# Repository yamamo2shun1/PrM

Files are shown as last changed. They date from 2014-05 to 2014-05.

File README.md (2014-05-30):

PrM
===

Modularized Analog mixer Controlled by Open Sound Control

License
---
<br /><span xmlns:dct="http://purl.org/dc/terms/" property="dct:title">PrM</span> is licensed under a <a rel="license" href="http://creativecommons.org/licenses/by-sa/4.0/">Creative Commons Attribution-ShareAlike 4.0 International License</a>.<br />Based on a work at <a xmlns:dct="http://purl.org/dc/terms/" href="https://github.com/tkrworks/PrM" rel="dct:source">https://github.com/tkrworks/PrM</a>.

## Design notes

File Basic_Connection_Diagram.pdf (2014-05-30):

Ch.1 | Ch.2

## Basic Module Connection Diagram

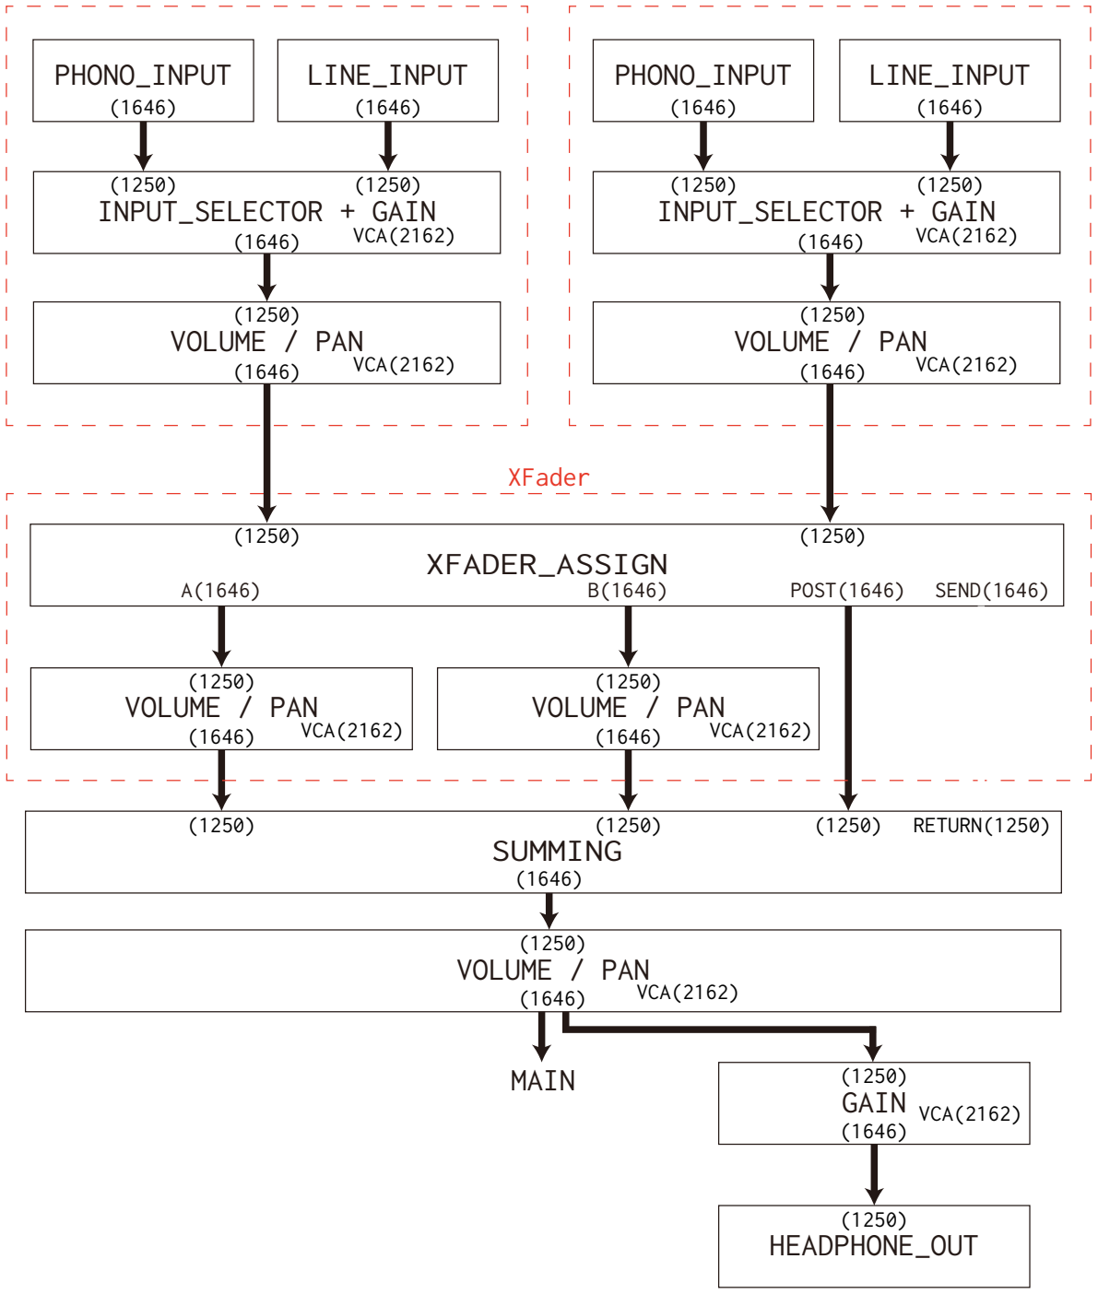
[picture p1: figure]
XFADER_ASSIGN; SUMMING; VOLUME / PAN; POST(1646) SEND(1646); MAIN; XFader; PHONO_INPUT (1646); LINE_INPUT (1646); (1250) RETURN(1250); INPUT_SELECTOR + GAIN (1646); VCA(2162); VOLUME / PAN (1646); HEADPHONE_OUT; GAIN (1646)

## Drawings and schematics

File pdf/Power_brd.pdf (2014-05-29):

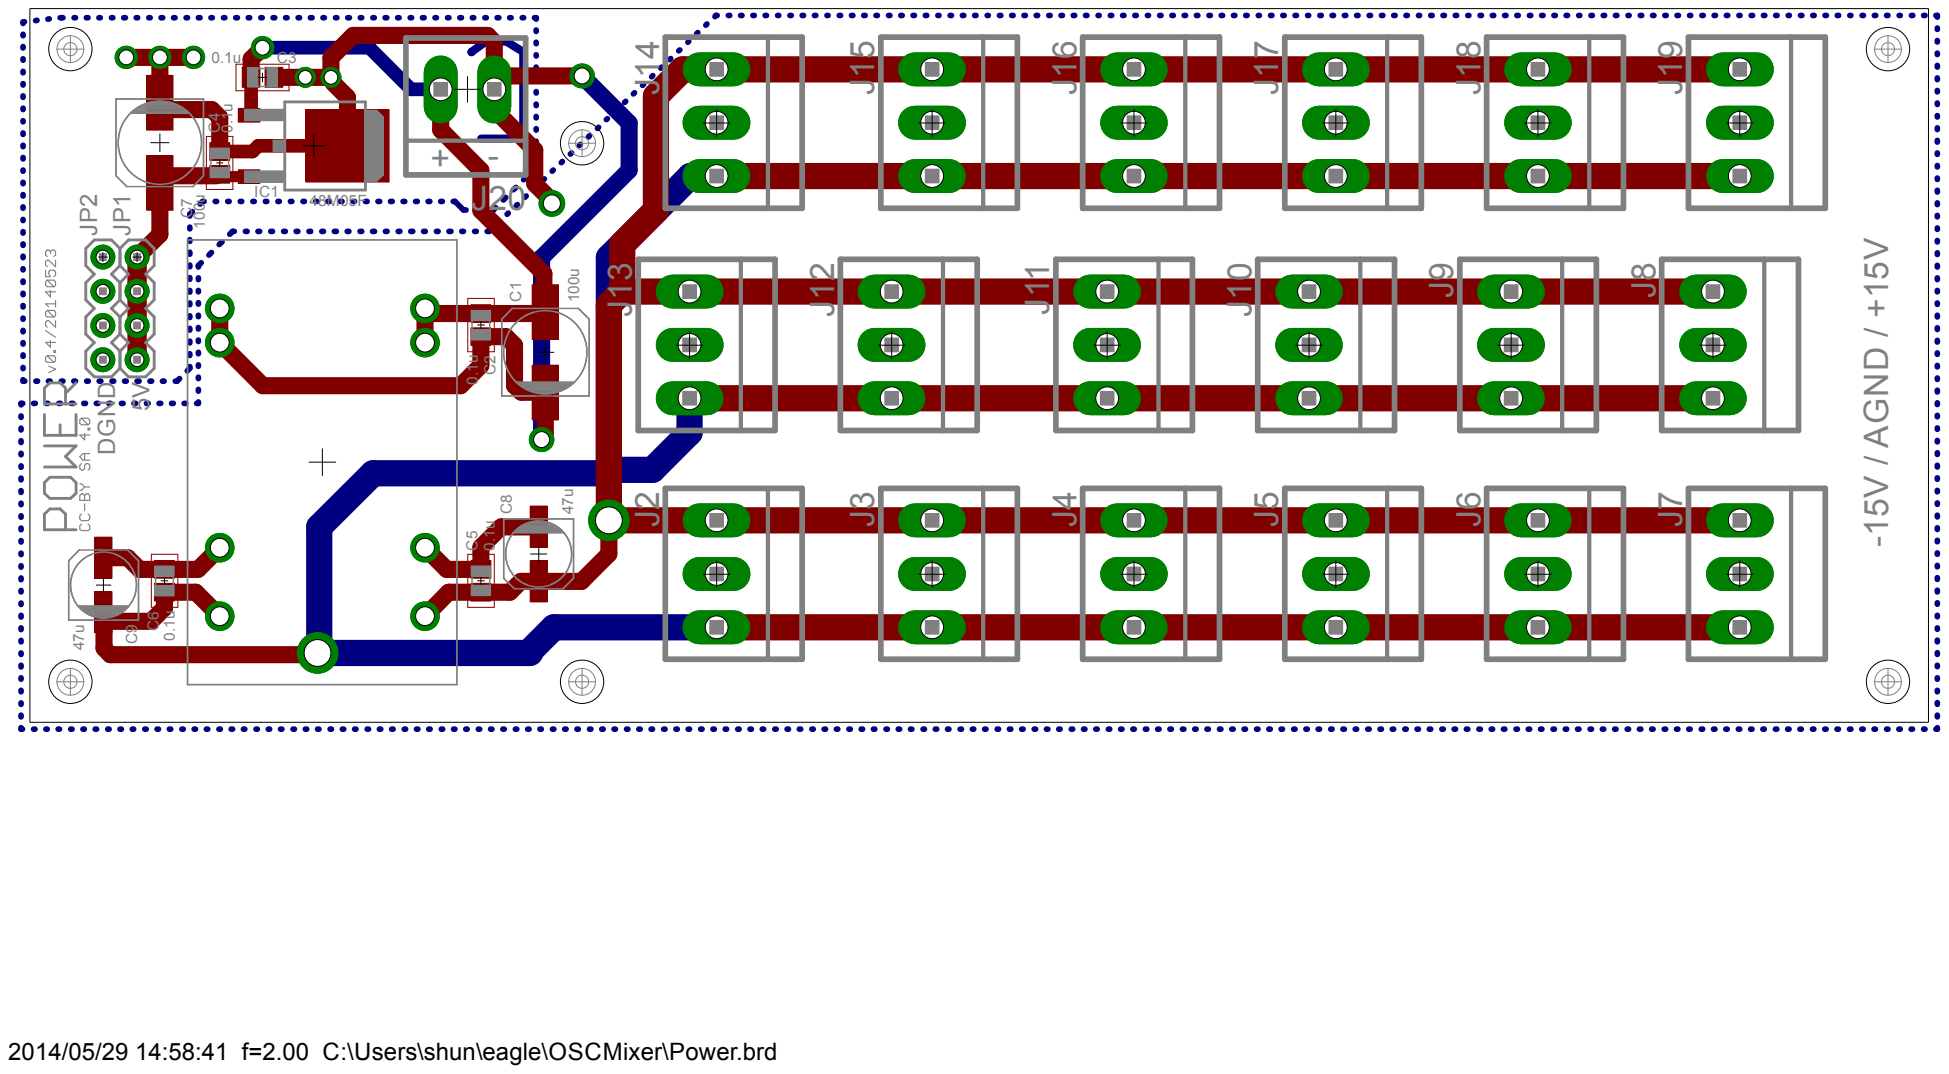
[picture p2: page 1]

2014/05/29 14:58:41 f=2.00 C:\Users\shun\eagle\OSCMixer\Power.brd

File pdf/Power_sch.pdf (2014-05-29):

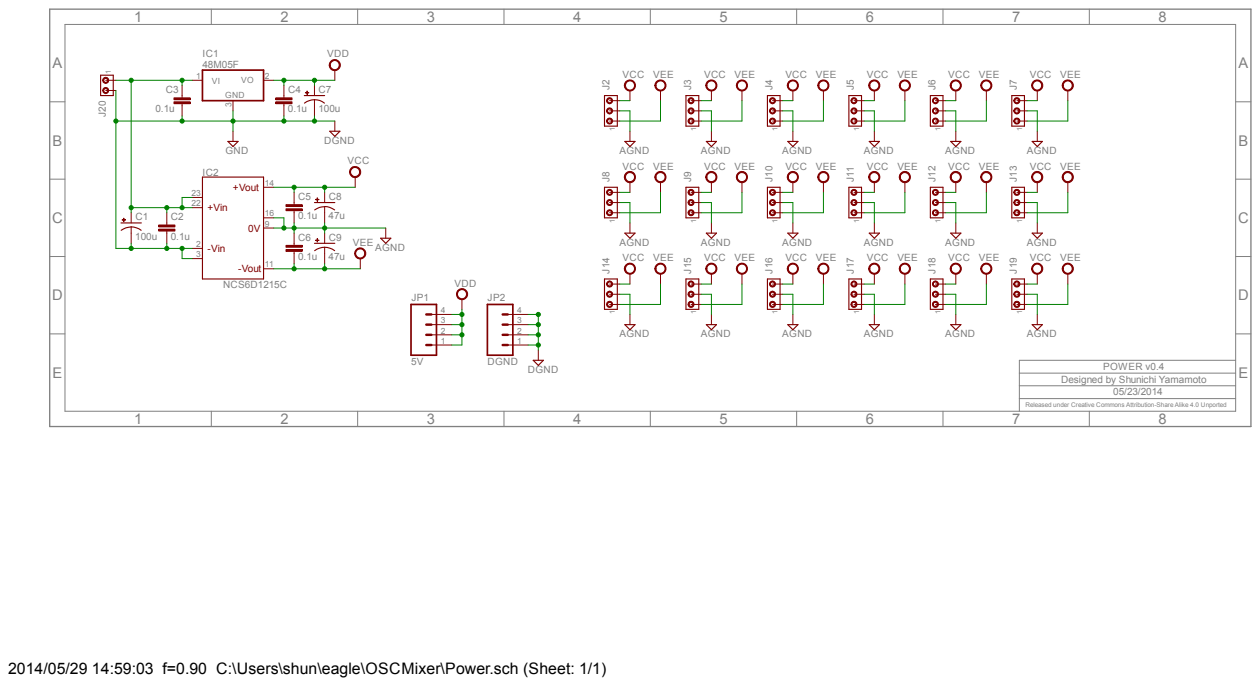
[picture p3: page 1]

Designed by Shunichi Yamamoto

Released under Creative Commons Attribution-Share Alike 4.0 Unported

2014/05/29 14:59:03 f=0.90 C:\Users\shun\eagle\OSCMixer\Power.sch (Sheet: 1/1)

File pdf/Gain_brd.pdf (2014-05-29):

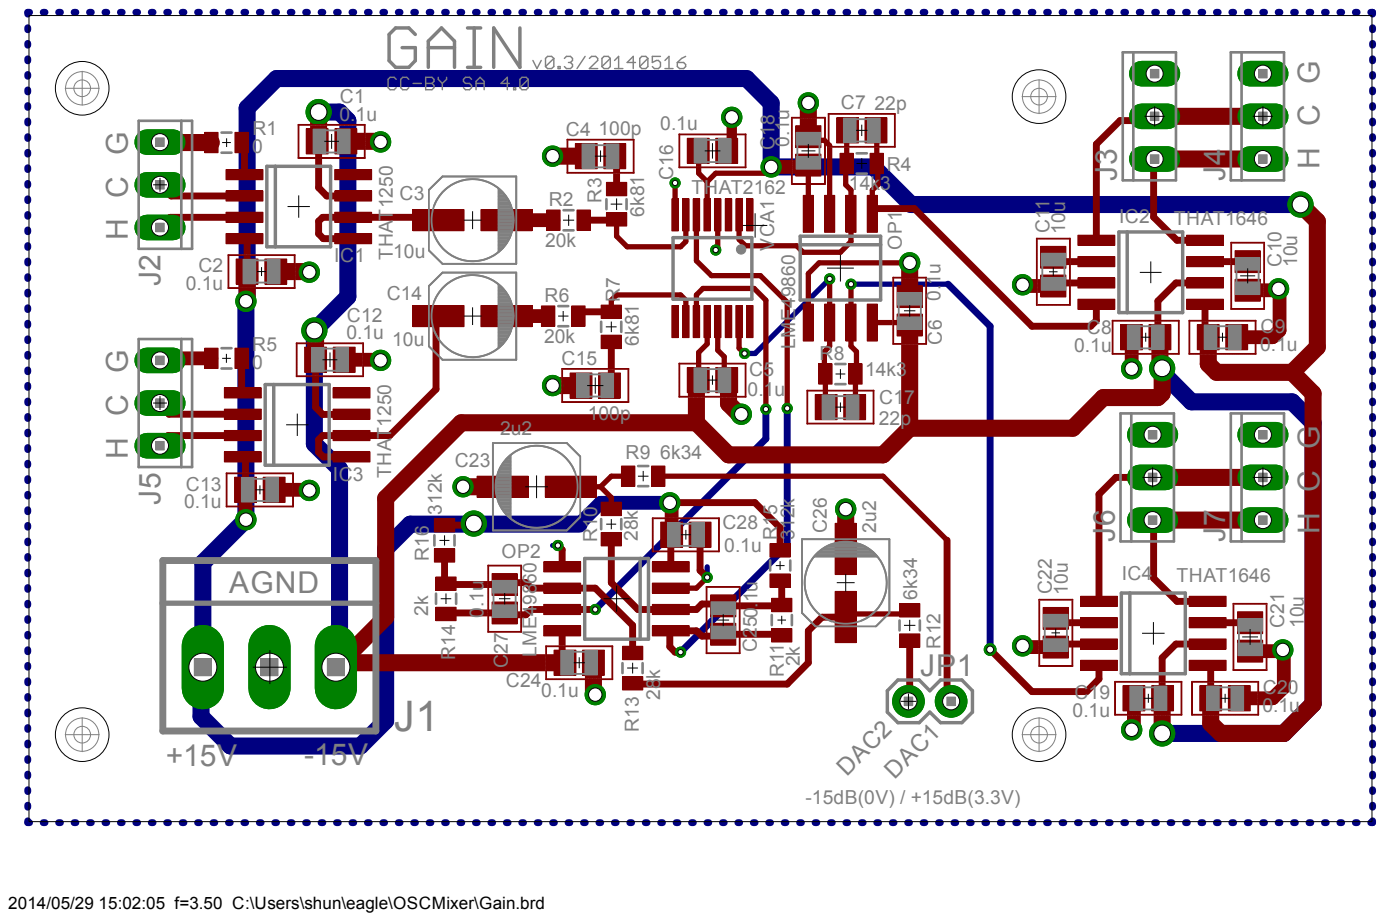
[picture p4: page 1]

2014/05/29 15:02:05 f=3.50 C:\Users\shun\eagle\OSCMixer\Gain.brd

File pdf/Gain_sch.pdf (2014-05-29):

1 | 2 | 3 | 4 | 5 | 6 | 7 | 8

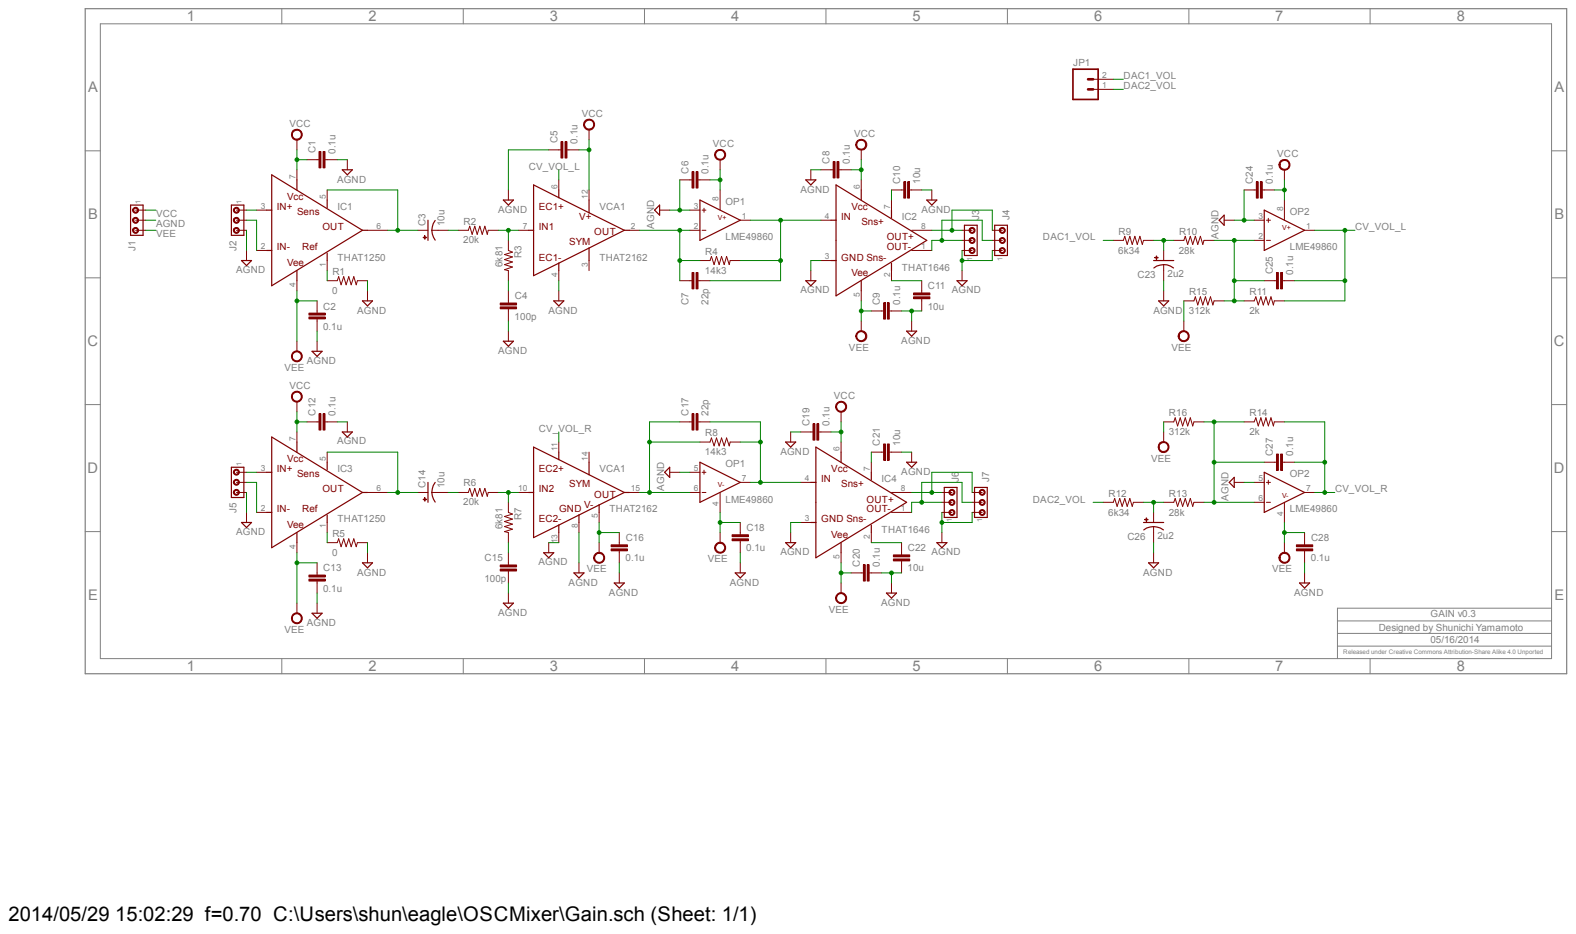
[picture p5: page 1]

Designed by Shunichi Yamamoto

Released under Creative Commons Attribution-Share Alike 4.0 Unported

2014/05/29 15:02:29 f=0.70 C:\Users\shun\eagle\OSCMixer\Gain.sch (Sheet: 1/1)

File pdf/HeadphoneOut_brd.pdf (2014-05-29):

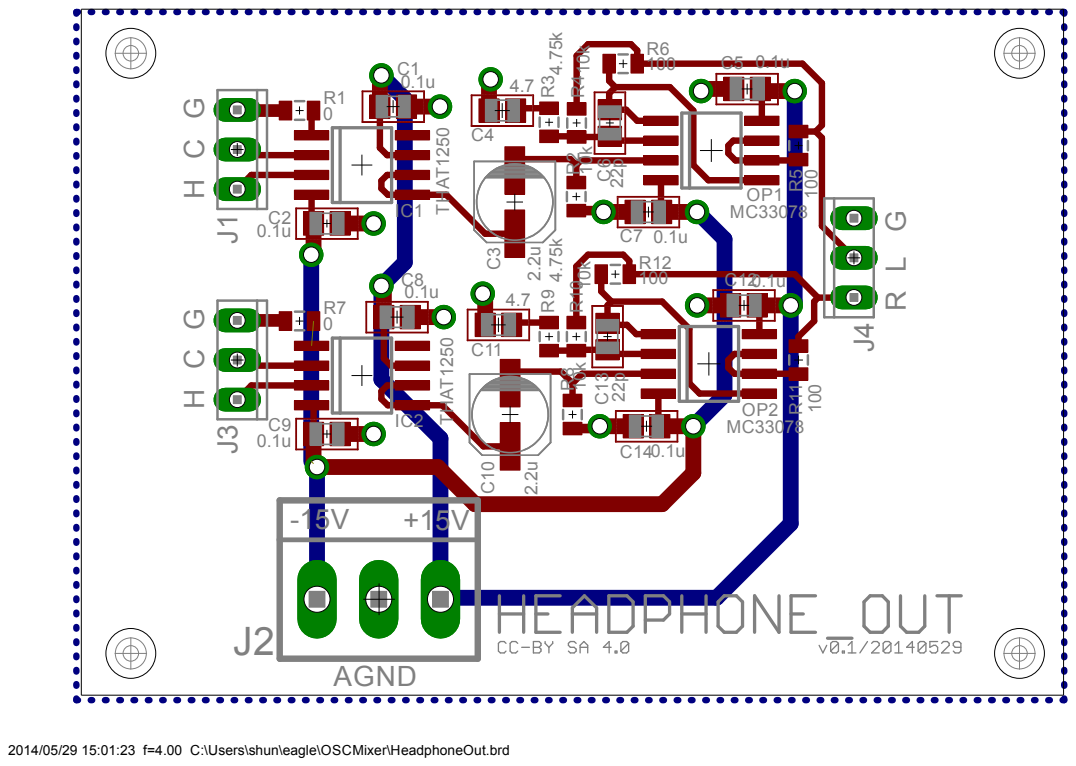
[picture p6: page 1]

2014/05/29 15:01:23 f=4.00 C:\Users\shun\eagle\OSCMixer\HeadphoneOut.brd

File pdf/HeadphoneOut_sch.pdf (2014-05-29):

A

A

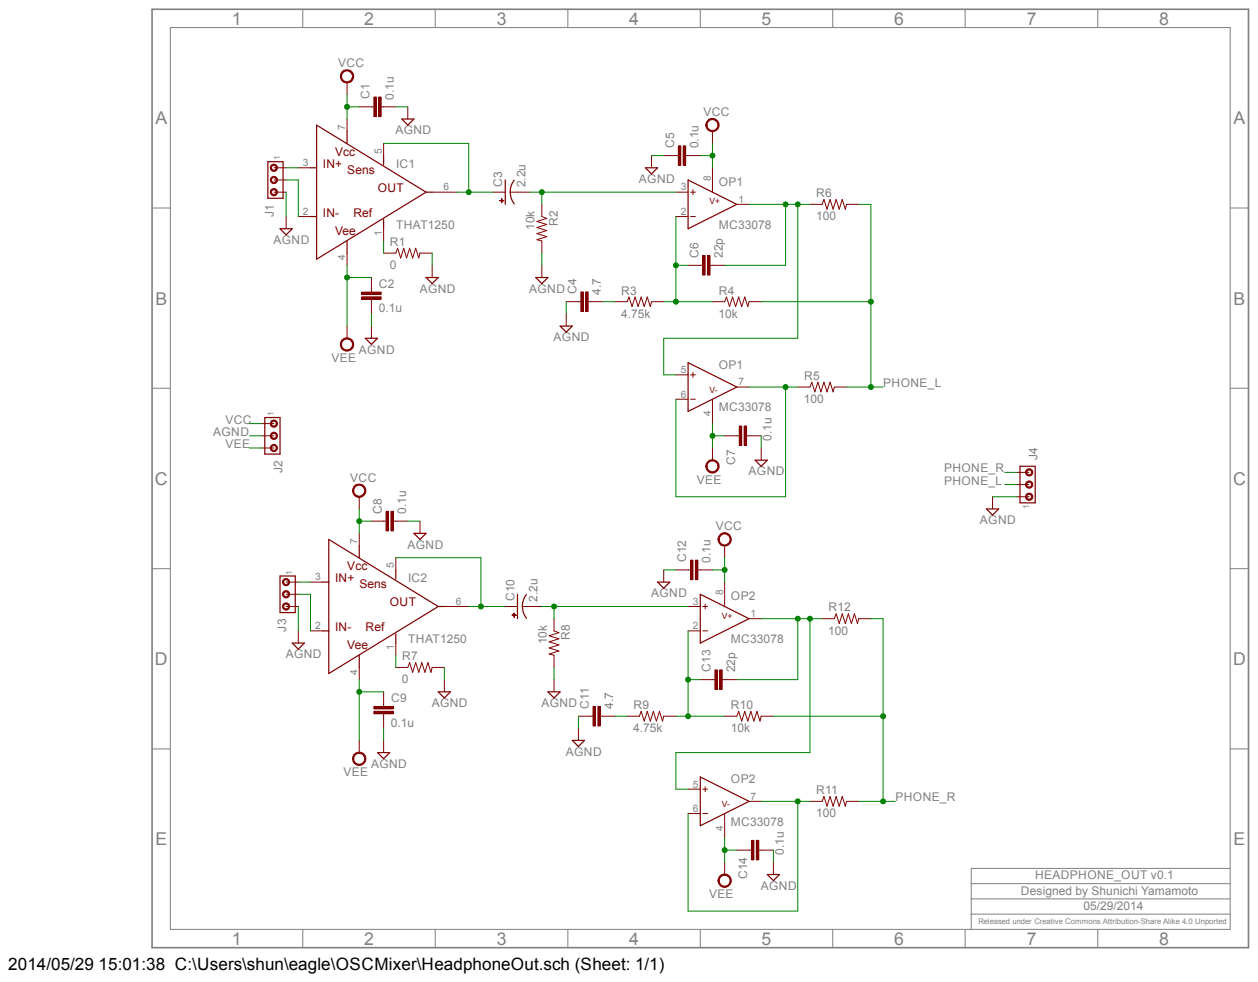
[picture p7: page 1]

HEADPHONE_OUT v0.1
Designed by Shunichi Yamamoto

Released under Creative Commons Attribution-Share Alike 4.0 Unported

2014/05/29 15:01:38 C:\Users\shun\eagle\OSCMixer\HeadphoneOut.sch (Sheet: 1/1)

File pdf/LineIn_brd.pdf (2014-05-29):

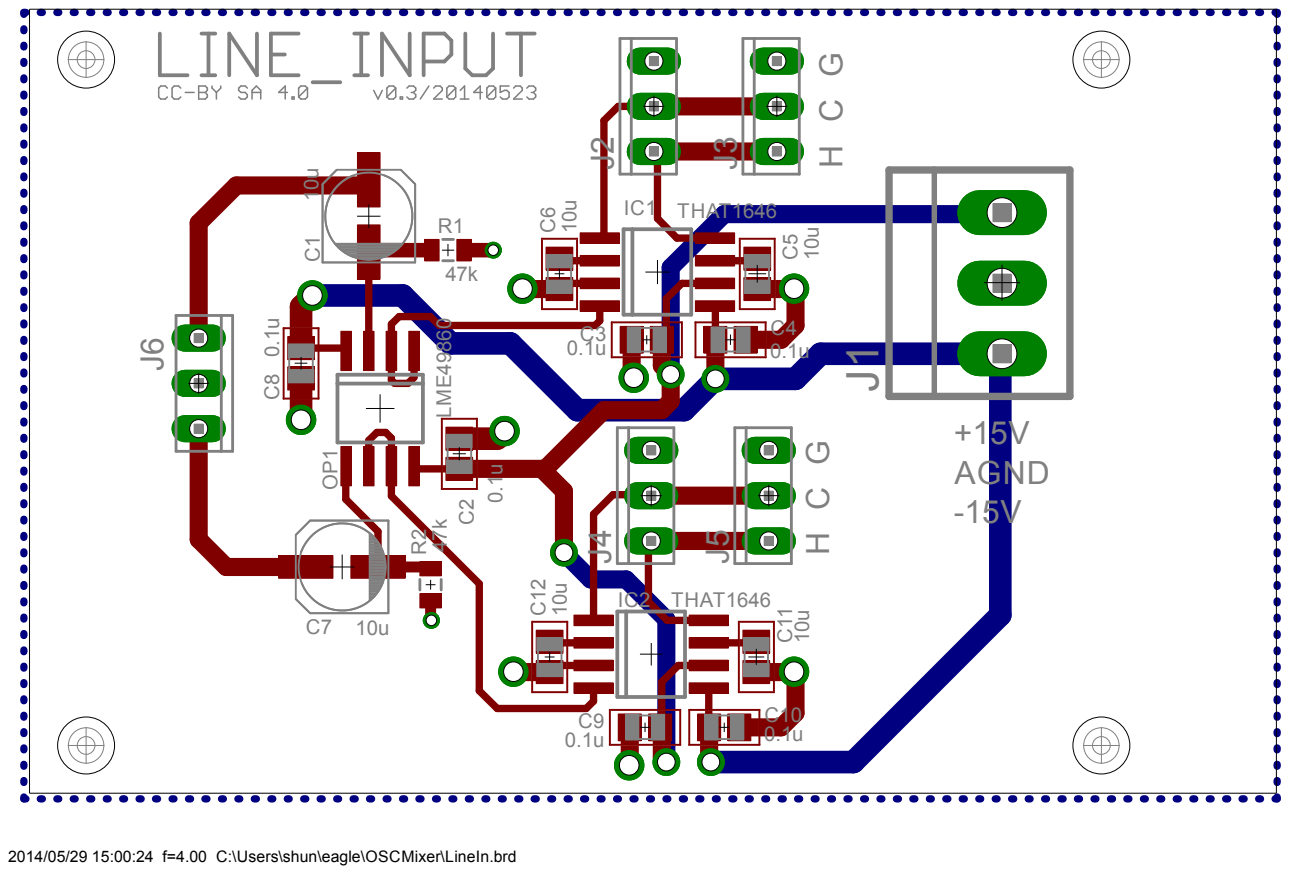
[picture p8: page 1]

2014/05/29 15:00:24 f=4.00 C:\Users\shun\eagle\OSCMixer\LineIn.brd

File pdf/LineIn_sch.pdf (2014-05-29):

A

A

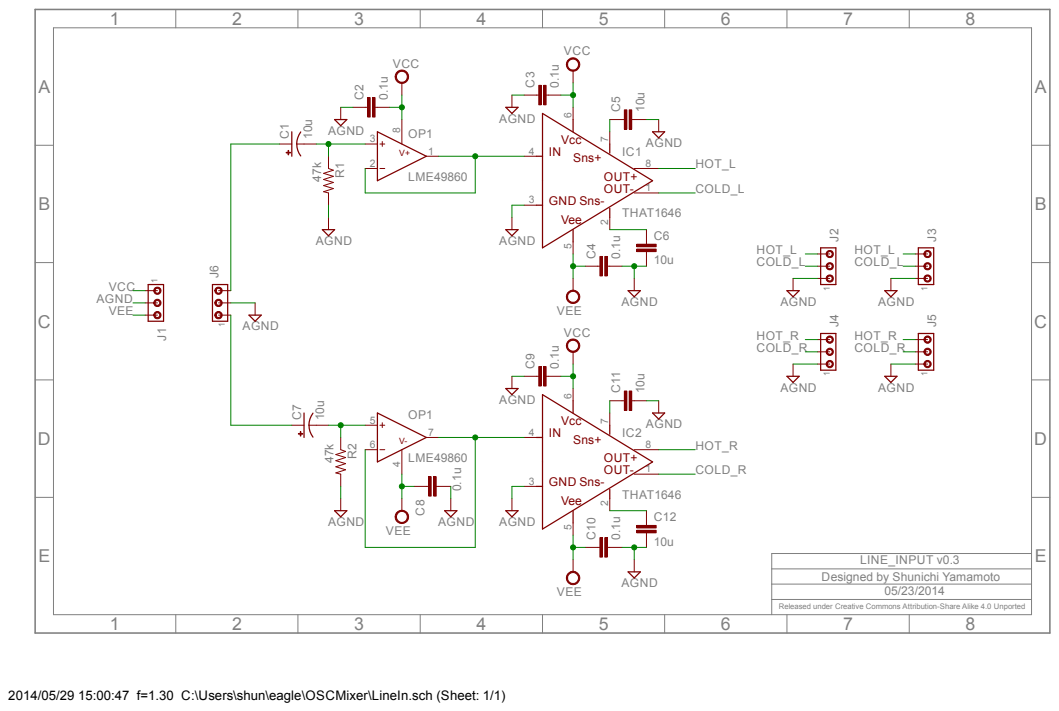
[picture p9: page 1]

VCC

LINE_INPUT v0.3
Designed by Shunichi Yamamoto

Released under Creative Commons Attribution-Share Alike 4.0 Unported

2014/05/29 15:00:47 f=1.30 C:\Users\shun\eagle\OSCMixer\LineIn.sch (Sheet: 1/1)

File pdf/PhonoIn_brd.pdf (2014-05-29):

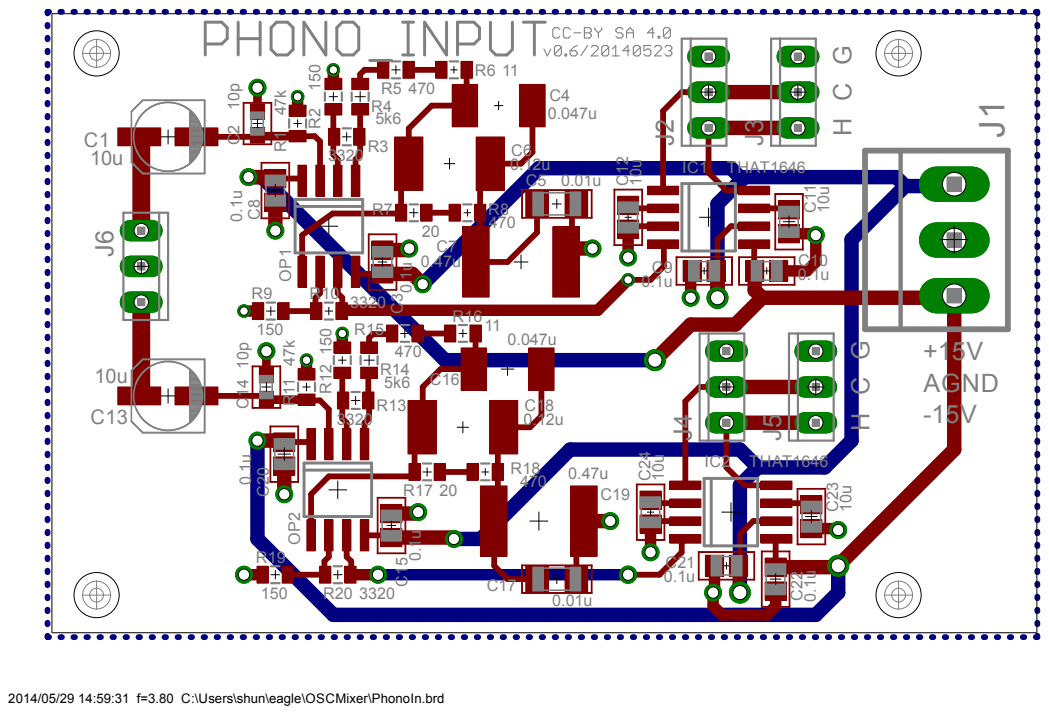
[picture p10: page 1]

2014/05/29 14:59:31 f=3.80 C:\Users\shun\eagle\OSCMixer\PhonoIn.brd

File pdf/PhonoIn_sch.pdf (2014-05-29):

A

A

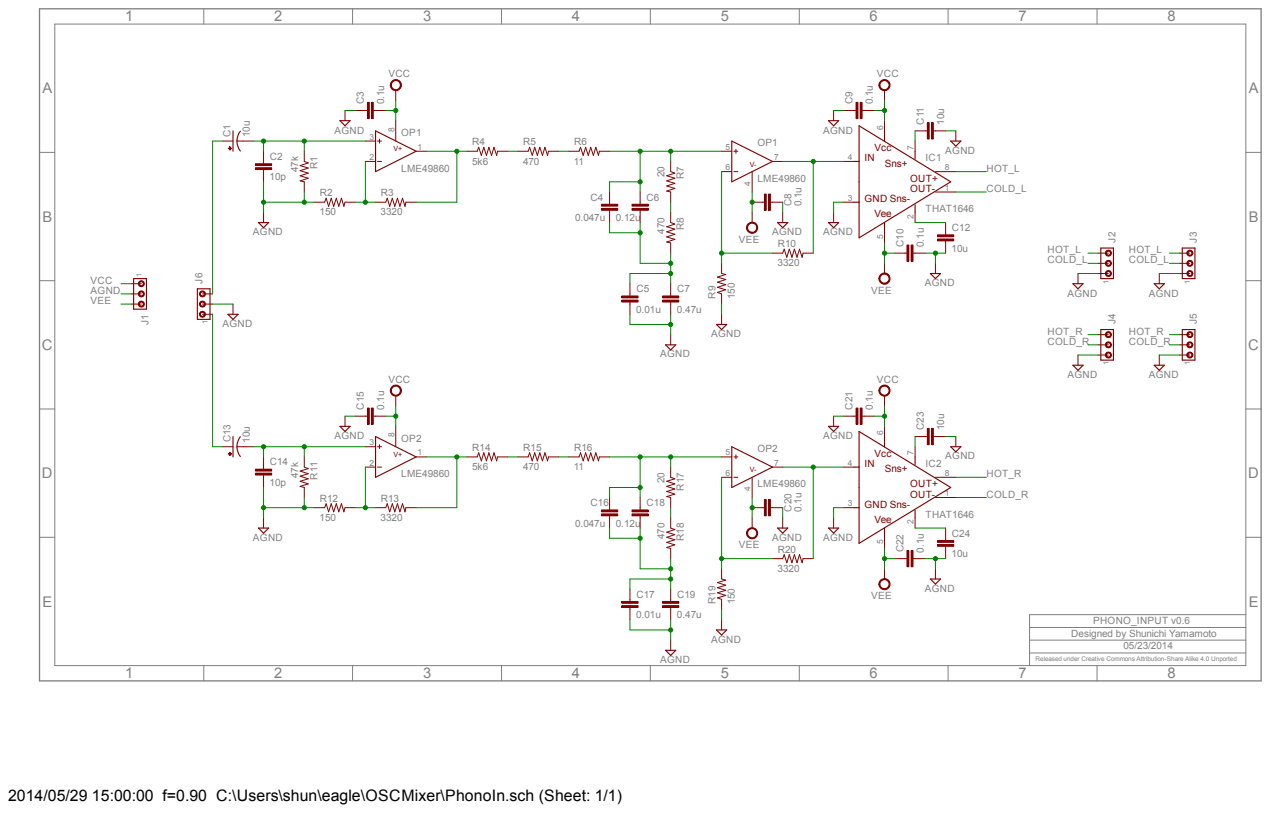
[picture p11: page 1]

VCC

PHONO_INPUT v0.6
Designed by Shunichi Yamamoto

Released under Creative Commons Attribution-Share Alike 4.0 Unported

2014/05/29 15:00:00 f=0.90 C:\Users\shun\eagle\OSCMixer\PhonoIn.sch (Sheet: 1/1)

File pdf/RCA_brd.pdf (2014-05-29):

X1

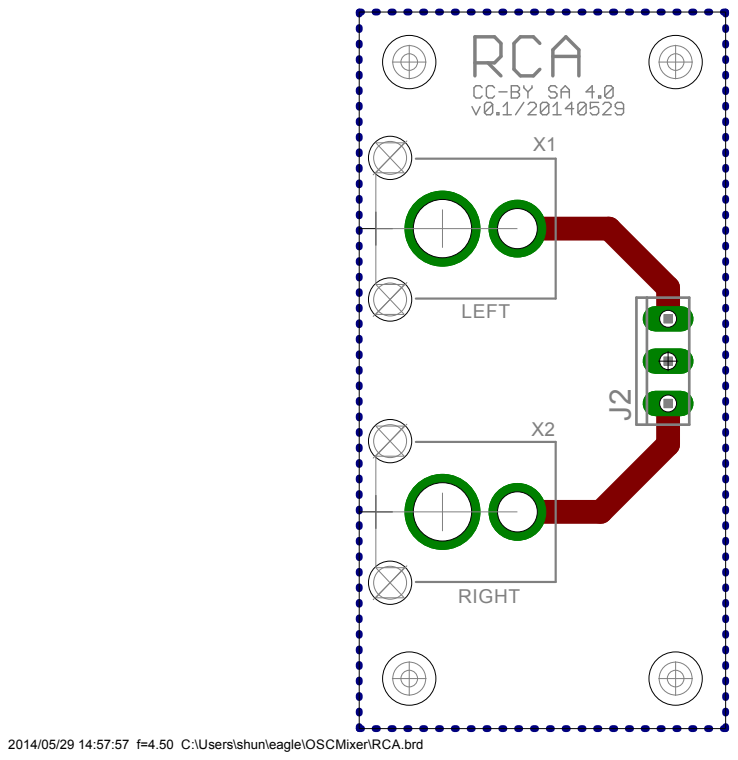
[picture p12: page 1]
LEFT; RIGHT

2014/05/29 14:57:57 f=4.50 C:\Users\shun\eagle\OSCMixer\RCA.brd

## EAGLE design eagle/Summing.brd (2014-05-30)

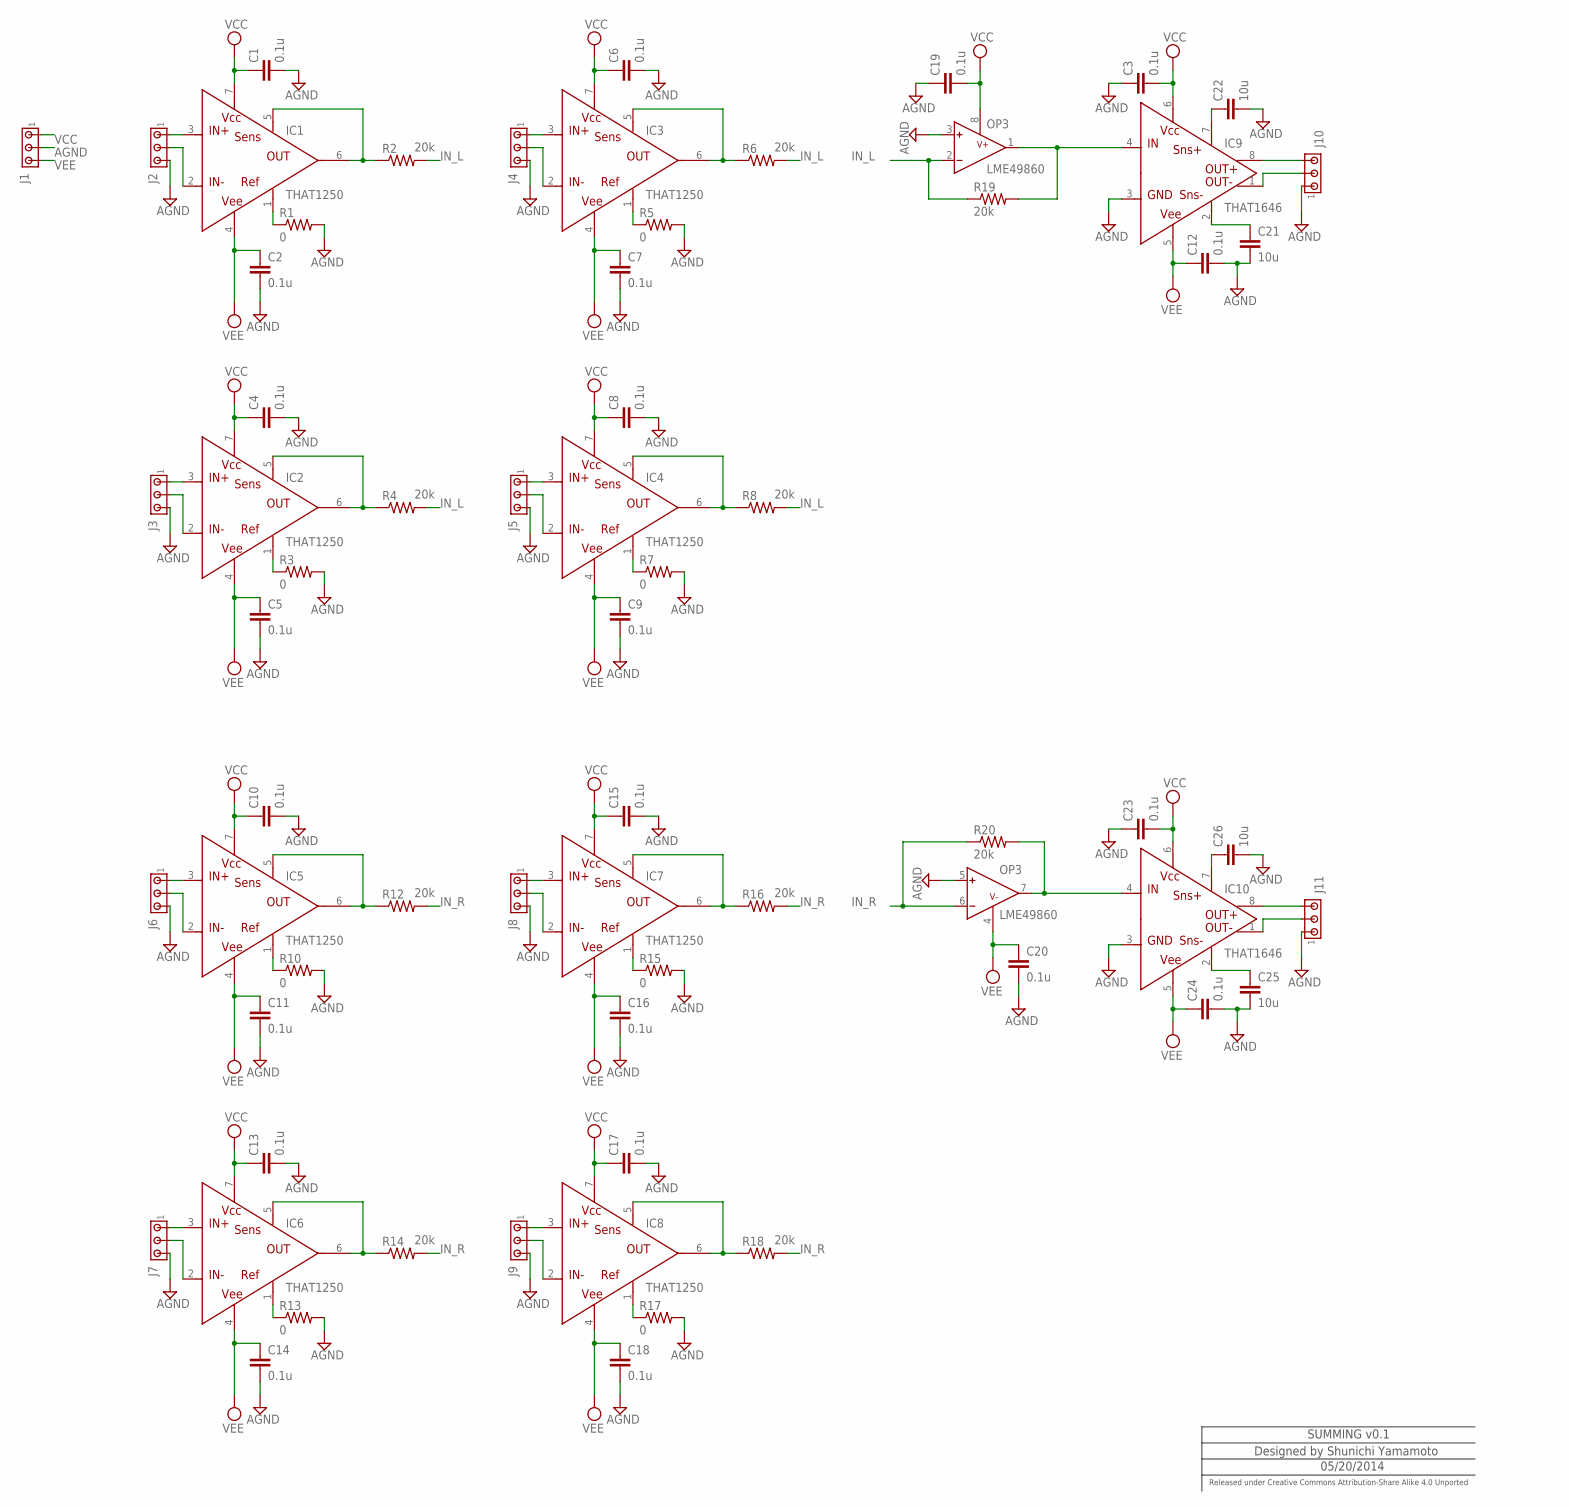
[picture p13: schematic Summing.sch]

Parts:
C1, C2, C3, C4, C5, C6, C7, C8, C9, C10, C11, C12, C13, C14, C15, C16, C17, C18, C19, C20, C23, C24: 0.1u; C2012
C21, C22, C25, C26: 10u; C2012
IC1, IC2, IC3, IC4, IC5, IC6, IC7, IC8: THAT1250; SOIC8@1
IC9, IC10: THAT1646; SOIC8
J1: MTA03-156; 1X3MTA
J2, J3, J4, J5, J6, J7, J8, J9, J10, J11: MTA03-100; 10X03MTA
OP3: LME49860; SOIC8@2
R1, R3, R5, R7, R10, R13, R15, R17: 0; 0805
R2, R4, R6, R8, R12, R14, R16, R18, R19, R20: 20k; 0805

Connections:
AGND: C1.2, C2.2, C3.1, C4.2, C5.2, C6.2, C7.2, C8.2, C9.2, C10.2, C11.2, C12.2, C13.2, C14.2, C15.2, C16.2, C17.2, C18.2, C19.1, C20.2, C21.2, C22.2, C23.1, C24.2, C25.2, C26.2, IC9.3 (GND), IC10.3 (GND), J1.2, J2.3, J3.3, J4.3, J5.3, J6.3, J7.3, J8.3, J9.3, J10.1, J11.1, OP3.3 (INA+), OP3.5 (INB+), R1.2, R3.2, R5.2, R7.2, R10.2, R13.2, R15.2, R17.2
IN_L: OP3.2 (INA-), R2.2, R4.2, R6.2, R8.2, R19.1
IN_R: OP3.6 (INB-), R12.2, R14.2, R16.2, R18.2, R20.1
MGAIN_L2: IC9.4 (IN), OP3.1 (OUTA), R19.2
MGAIN_R: IC10.4 (IN), OP3.7 (OUTB), R20.2
unnamed: IC1.1 (REF), R1.1
unnamed: IC2.1 (REF), R3.1
unnamed: IC1.3 (IN+), J2.1
unnamed: IC1.2 (IN-), J2.2
unnamed: IC2.3 (IN+), J3.1
unnamed: IC2.2 (IN-), J3.2
unnamed: IC3.1 (REF), R5.1
unnamed: IC3.3 (IN+), J4.1
unnamed: IC3.2 (IN-), J4.2
unnamed: IC4.1 (REF), R7.1
unnamed: IC4.3 (IN+), J5.1
unnamed: IC4.2 (IN-), J5.2
unnamed: IC5.1 (REF), R10.1
unnamed: IC5.3 (IN+), J6.1
unnamed: IC5.2 (IN-), J6.2
unnamed: IC6.1 (REF), R13.1
unnamed: IC6.3 (IN+), J7.1
unnamed: IC6.2 (IN-), J7.2
unnamed: IC7.1 (REF), R15.1
unnamed: IC7.3 (IN+), J8.1
unnamed: IC7.2 (IN-), J8.2
unnamed: IC8.1 (REF), R17.1
unnamed: IC8.3 (IN+), J9.1
unnamed: IC8.2 (IN-), J9.2
unnamed: C22.1, IC9.7 (SNS+)
unnamed: IC9.8 (OUT+), J10.3
unnamed: IC9.1 (OUT-), J10.2
unnamed: C26.1, IC10.7 (SNS+)
unnamed: C25.1, IC10.2 (SNS-)
unnamed: IC10.8 (OUT+), J11.3
unnamed: IC10.1 (OUT-), J11.2
unnamed: C21.1, IC9.2 (SNS-)
PIN_L: IC1.5 (SENS), IC1.6 (OUT), R2.1
PIN_L1: IC2.5 (SENS), IC2.6 (OUT), R4.1
PIN_L2: IC3.5 (SENS), IC3.6 (OUT), R6.1
PIN_L3: IC4.5 (SENS), IC4.6 (OUT), R8.1
PIN_L4: IC5.5 (SENS), IC5.6 (OUT), R12.1
PIN_L5: IC6.5 (SENS), IC6.6 (OUT), R14.1
PIN_L6: IC7.5 (SENS), IC7.6 (OUT), R16.1
PIN_L7: IC8.5 (SENS), IC8.6 (OUT), R18.1
VCC: C1.1, C3.2, C4.1, C6.1, C8.1, C10.1, C13.1, C15.1, C17.1, C19.2, C23.2, IC1.7 (VCC), IC2.7 (VCC), IC3.7 (VCC), IC4.7 (VCC), IC5.7 (VCC), IC6.7 (VCC), IC7.7 (VCC), IC8.7 (VCC), IC9.6 (VCC), IC10.6 (VCC), J1.1, OP3.8 (V+)
VEE: C2.1, C5.1, C7.1, C9.1, C11.1, C12.1, C14.1, C16.1, C18.1, C20.1, C24.1, IC1.4 (VEE), IC2.4 (VEE), IC3.4 (VEE), IC4.4 (VEE), IC5.4 (VEE), IC6.4 (VEE), IC7.4 (VEE), IC8.4 (VEE), IC9.5 (VEE), IC10.5 (VEE), J1.3, OP3.4 (V-)

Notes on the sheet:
SUMMING v0.1
Designed by Shunichi Yamamoto
05/20/2014
Released under Creative Commons Attribution-Share Alike 4.0 Unported

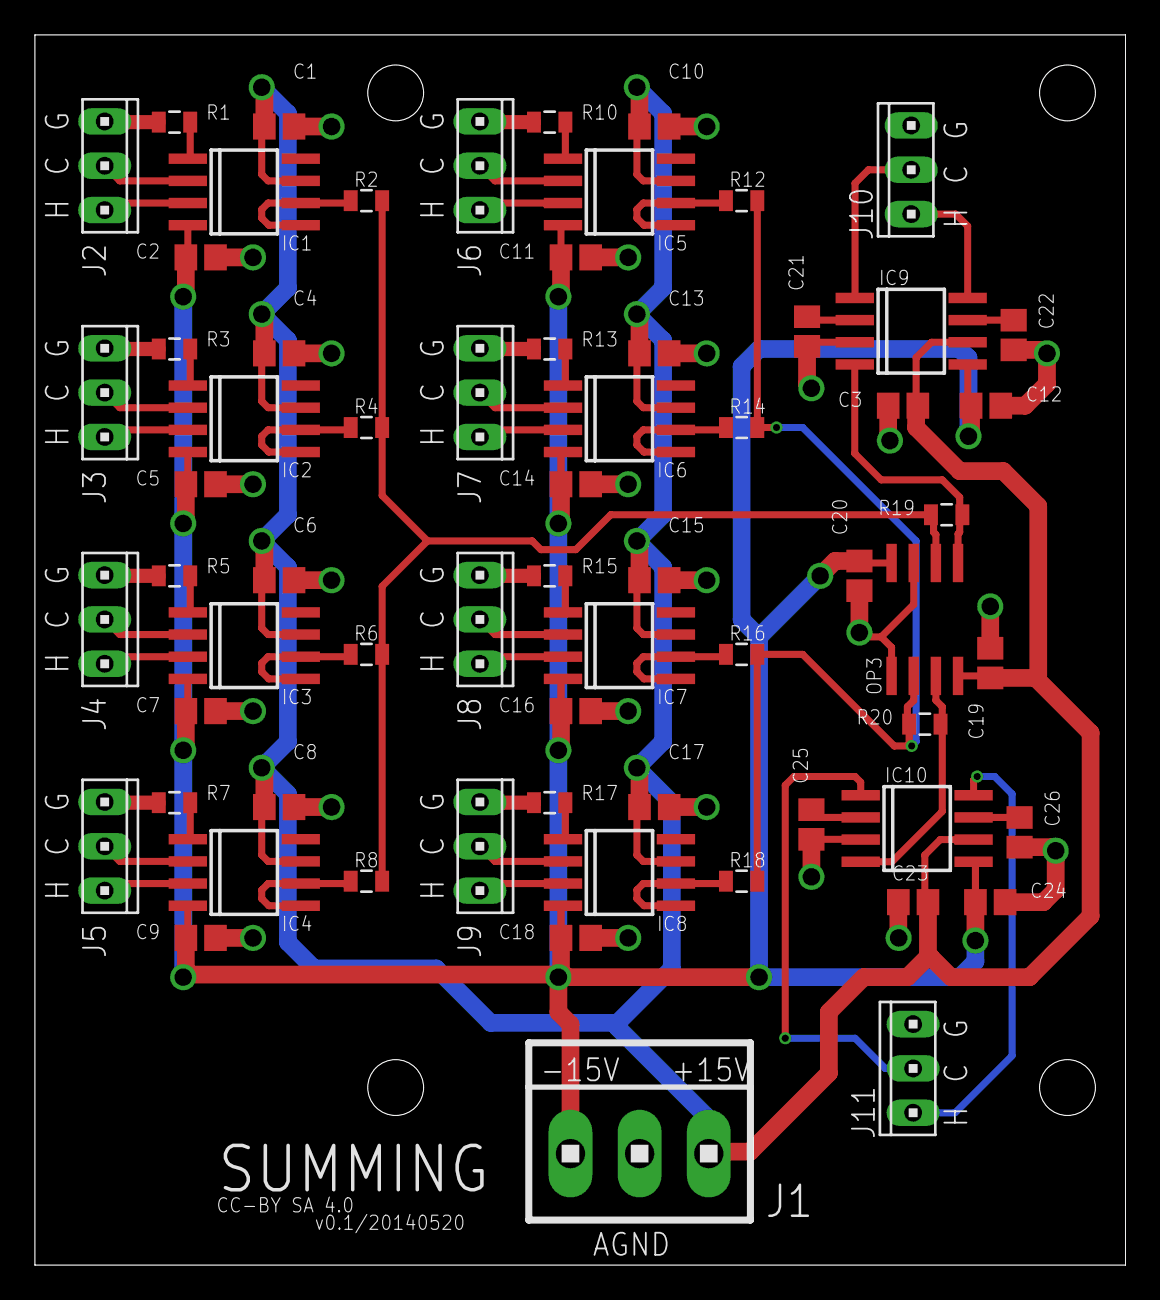
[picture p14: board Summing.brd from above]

Board: 4 copper layers, 62.5 x 70.5 mm, 66 parts (0 on the bottom side), 47 nets.

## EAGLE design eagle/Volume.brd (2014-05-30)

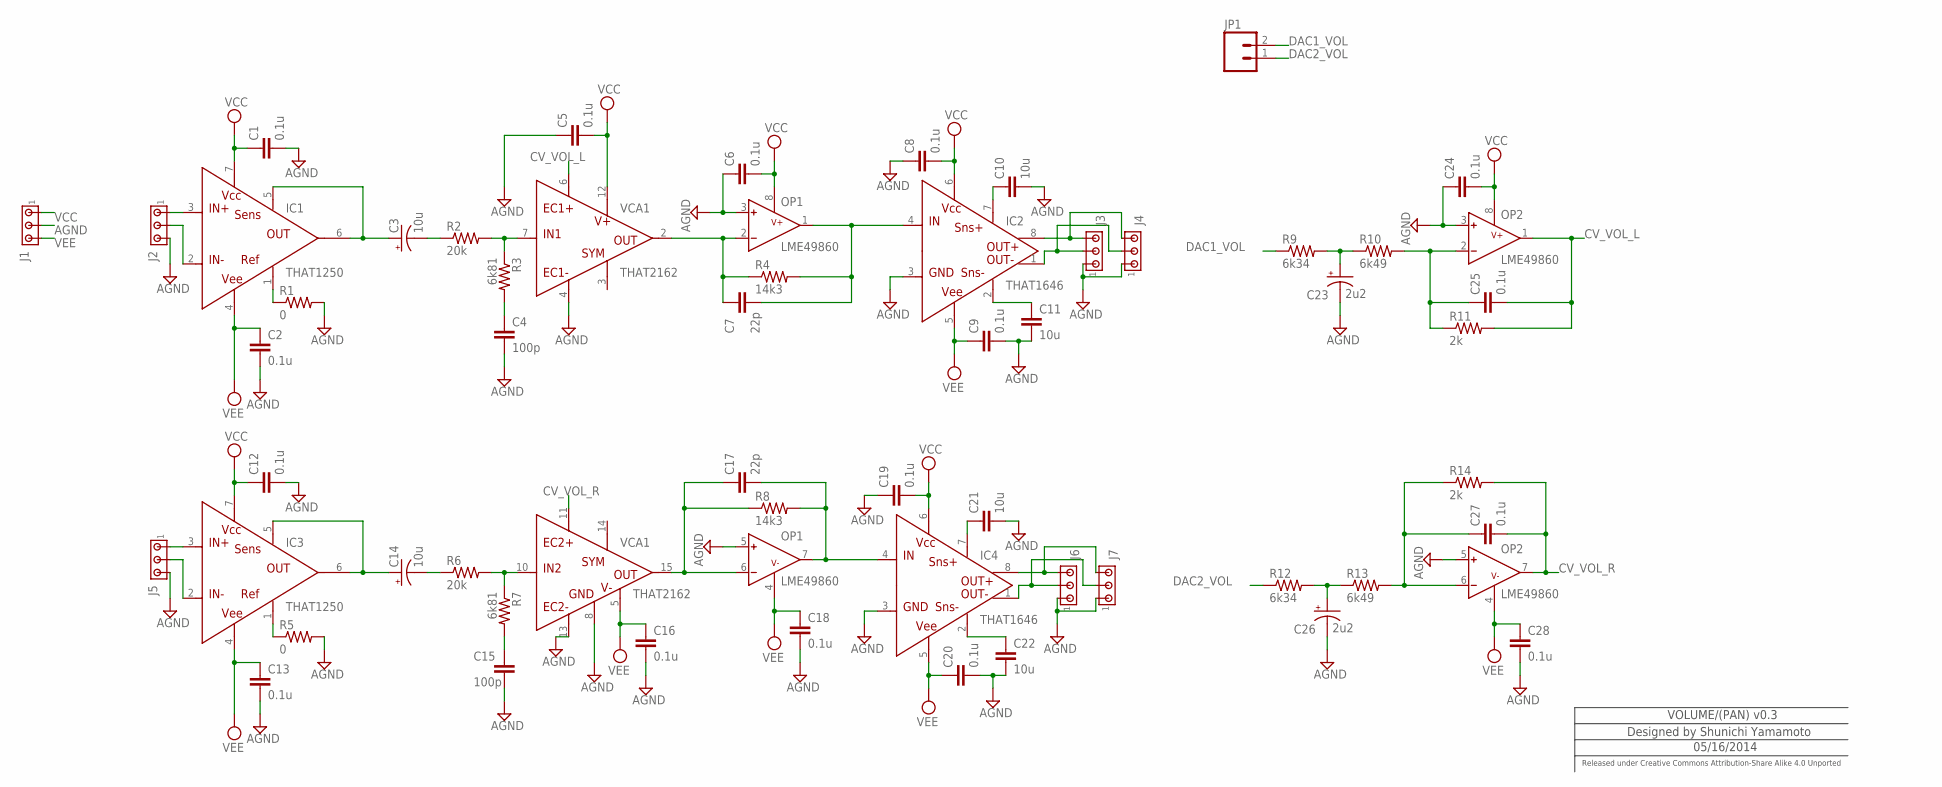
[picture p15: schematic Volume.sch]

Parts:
C1, C2, C5, C6, C8, C9, C12, C13, C16, C18, C19, C20, C24, C25, C27, C28: 0.1u; C2012
C3, C14: 10u; UD-5X5,8_NICHICON
C4, C15: 100p; C2012
C7, C17: 22p; C2012
C10, C11, C21, C22: 10u; C2012
C23, C26: 2u2; UD-5X5,8_NICHICON
IC1, IC3: THAT1250; SOIC8
IC2, IC4: THAT1646; SOIC8
J1: MTA03-156; 1X3MTA
J2, J3, J4, J5, J6, J7: MTA03-100; 10X03MTA
JP1: M02PTH; 1X02
OP1, OP2: LME49860; SOIC8@1
R1, R5: 0; 0805
R2, R6: 20k; 0805
R3, R7: 6k81; 0805
R4, R8: 14k3; 0805
R9, R12: 6k34; 0805
R10, R13: 6k49; 0805
R11, R14: 2k; 0805
VCA1: THAT2162; QSOP-16

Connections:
AGND: C1.2, C2.2, C4.2, C5.1, C6.1, C8.1, C9.2, C10.2, C11.2, C12.2, C13.2, C15.2, C16.2, C18.2, C19.1, C20.2, C21.2, C22.2, C23.-, C24.1, C26.-, C28.2, IC2.3 (GND), IC4.3 (GND), J1.2, J2.3, J3.1, J4.1, J5.3, J6.1, J7.1, OP1.3 (INA+), OP1.5 (INB+), OP2.3 (INA+), OP2.5 (INB+), R1.2, R5.2, VCA1.4 (EC1-), VCA1.8 (GND), VCA1.13 (EC2-)
C8: C14.-, R6.1
CV_VOL_L: C25.2, OP2.1 (OUTA), R11.2, VCA1.6 (EC1+)
CV_VOL_R: C27.2, OP2.7 (OUTB), R14.2, VCA1.11 (EC2+)
DAC1_VOL: JP1.2, R9.1
DAC2_VOL: JP1.1, R12.1
unnamed: IC1.1 (REF), R1.1
unnamed: C10.1, IC2.7 (SNS+)
unnamed: IC1.3 (IN+), J2.1
unnamed: IC1.2 (IN-), J2.2
unnamed: IC3.1 (REF), R5.1
unnamed: IC3.3 (IN+), J5.1
unnamed: IC3.2 (IN-), J5.2
unnamed: IC2.8 (OUT+), J3.3, J4.3
unnamed: IC2.1 (OUT-), J3.2, J4.2
unnamed: IC4.8 (OUT+), J6.3, J7.3
unnamed: IC4.1 (OUT-), J6.2, J7.2
unnamed: R2.2, R3.1, VCA1.7 (IN1)
unnamed: C11.1, IC2.2 (SNS-)
unnamed: C21.1, IC4.7 (SNS+)
unnamed: C22.1, IC4.2 (SNS-)
unnamed: C3.-, R2.1
unnamed: R6.2, R7.1, VCA1.10 (IN2)
unnamed: C7.1, OP1.2 (INA-), R4.1, VCA1.2 (OUT1)
unnamed: C4.1, R3.2
unnamed: C15.1, R7.2
unnamed: C23.+, R9.2, R10.1
unnamed: C25.1, OP2.2 (INA-), R10.2, R11.1
unnamed: C26.+, R12.2, R13.1
unnamed: C27.1, OP2.6 (INB-), R13.2, R14.1
unnamed: C17.1, OP1.6 (INB-), R8.1, VCA1.15 (OUT2)
OUT_L: C7.2, IC2.4 (IN), OP1.1 (OUTA), R4.2
OUT_R: C17.2, IC4.4 (IN), OP1.7 (OUTB), R8.2
PIN_L: C3.+, IC1.5 (SENS), IC1.6 (OUT)
PIN_R: C14.+, IC3.5 (SENS), IC3.6 (OUT)
VCC: C1.1, C5.2, C6.2, C8.2, C12.1, C19.2, C24.2, IC1.7 (VCC), IC2.6 (VCC), IC3.7 (VCC), IC4.6 (VCC), J1.1, OP1.8 (V+), OP2.8 (V+), VCA1.12 (V+)
VEE: C2.1, C9.1, C13.1, C16.1, C18.1, C20.1, C28.1, IC1.4 (VEE), IC2.5 (VEE), IC3.4 (VEE), IC4.5 (VEE), J1.3, OP1.4 (V-), OP2.4 (V-), VCA1.5 (V-)

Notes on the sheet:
VOLUME/(PAN) v0.3
Designed by Shunichi Yamamoto
05/16/2014
Released under Creative Commons Attribution-Share Alike 4.0 Unported

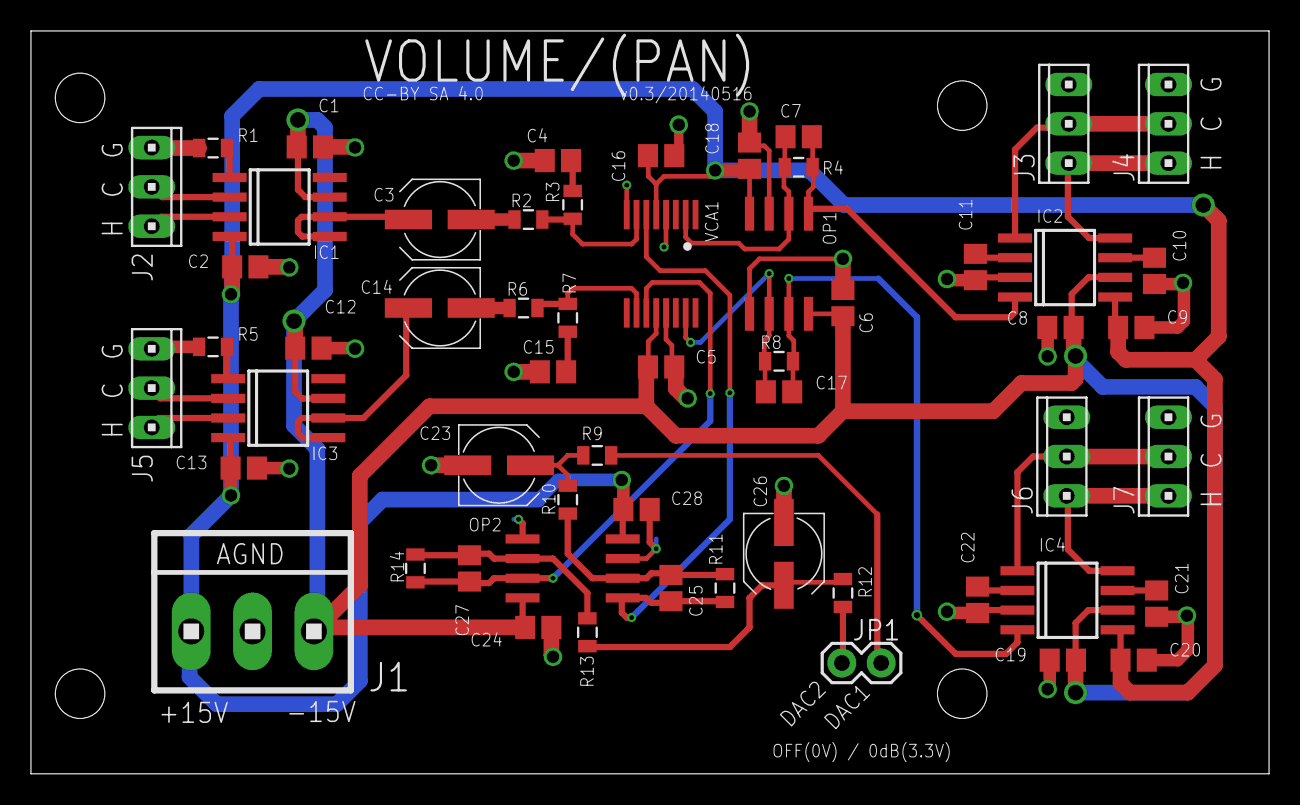
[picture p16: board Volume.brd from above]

Board: 2 copper layers, 80.0 x 48.0 mm, 57 parts (0 on the bottom side), 37 nets.

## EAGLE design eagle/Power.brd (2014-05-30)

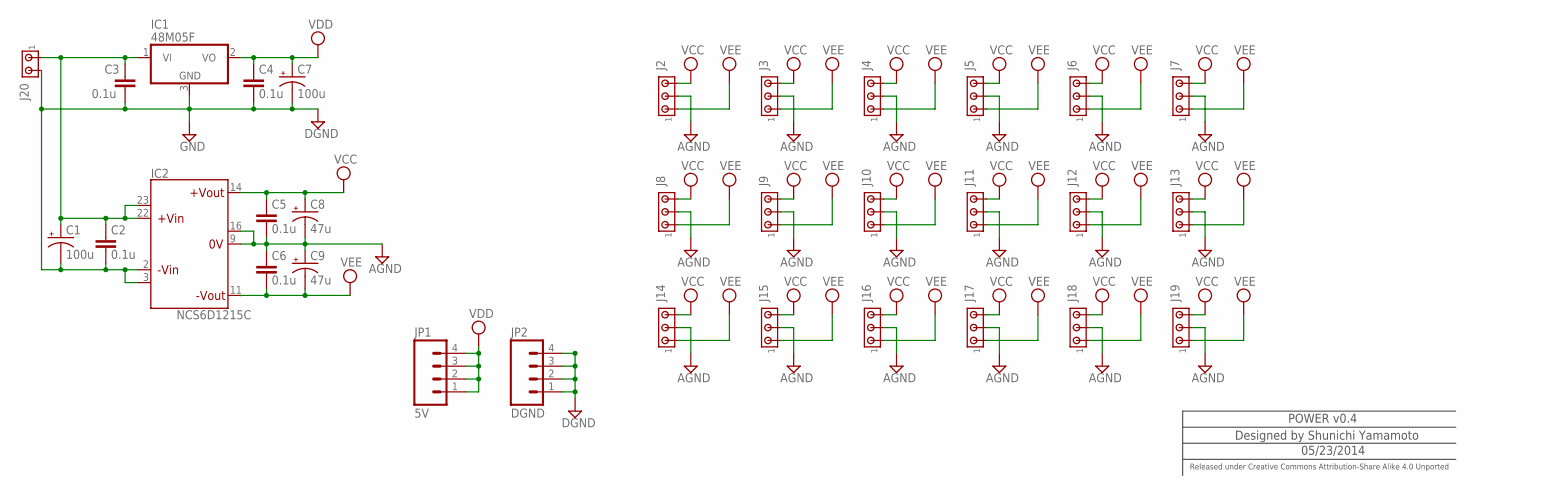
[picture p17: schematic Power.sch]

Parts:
C1, C7: 100u; UD-6,3X7,7_NICHICON
C2, C3, C4, C5, C6: 0.1u; C2012
C8, C9: 47u; UD-5X5,8_NICHICON
IC1: 48M05F; TO252
IC2: NCS6D1215C
J2, J3, J4, J5, J6, J7, J8, J9, J10, J11, J12, J13, J14, J15, J16, J17, J18, J19: MTA03-156; 1X3MTA
J20: MTA02-156; 1X2MTA
JP1: 5V; 1X04
JP2: DGND; 1X04

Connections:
AGND: C5.2, C6.1, C8.-, C9.+, IC2.9 (0V), IC2.16 (0V2), J2.2, J3.2, J4.2, J5.2, J6.2, J7.2, J8.2, J9.2, J10.2, J11.2, J12.2, J13.2, J14.2, J15.2, J16.2, J17.2, J18.2, J19.2
GND: C1.-, C2.2, C3.2, C4.2, C7.-, IC1.3 (GND), IC2.2 (-VIN), IC2.3 (-VIN2), J20.2, JP2.1, JP2.2, JP2.3, JP2.4
unnamed: C1.+, C2.1, C3.1, IC1.1 (VI), IC2.22 (+VIN), IC2.23 (+VIN2), J20.1
VCC: C5.1, C8.+, IC2.14 (+VOUT), J2.3, J3.3, J4.3, J5.3, J6.3, J7.3, J8.3, J9.3, J10.3, J11.3, J12.3, J13.3, J14.3, J15.3, J16.3, J17.3, J18.3, J19.3
VDD: C4.1, C7.+, IC1.2 (VO), JP1.1, JP1.2, JP1.3, JP1.4
VEE: C6.2, C9.-, IC2.11 (-VOUT), J2.1, J3.1, J4.1, J5.1, J6.1, J7.1, J8.1, J9.1, J10.1, J11.1, J12.1, J13.1, J14.1, J15.1, J16.1, J17.1, J18.1, J19.1

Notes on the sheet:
POWER v0.4
Designed by Shunichi Yamamoto
05/23/2014
Released under Creative Commons Attribution-Share Alike 4.0 Unported

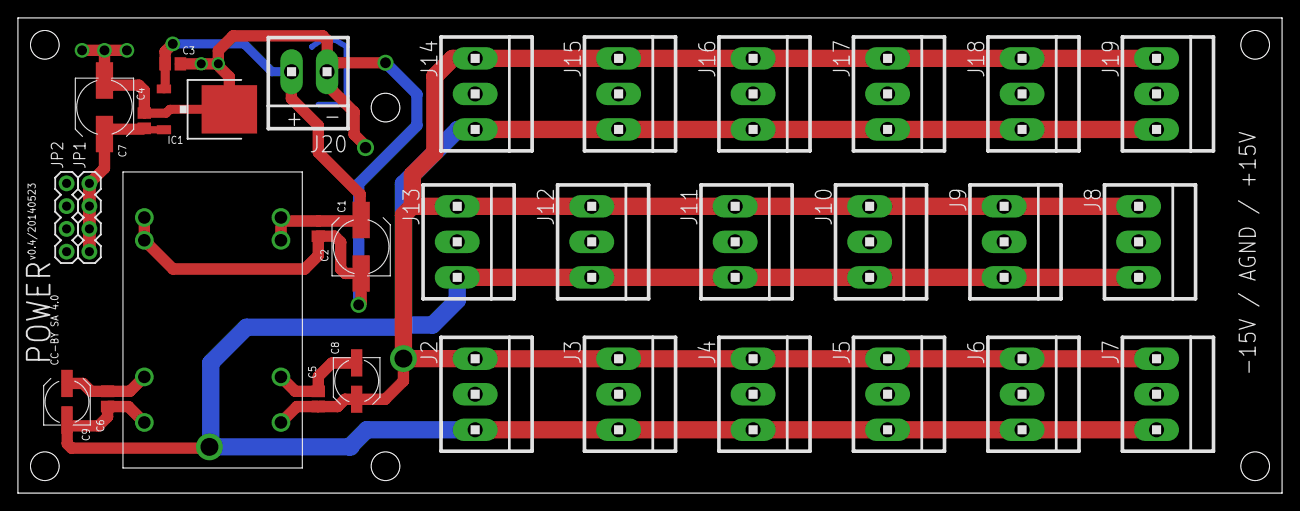
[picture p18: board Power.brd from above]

Board: 2 copper layers, 141.0 x 53.0 mm, 32 parts (0 on the bottom side), 6 nets.

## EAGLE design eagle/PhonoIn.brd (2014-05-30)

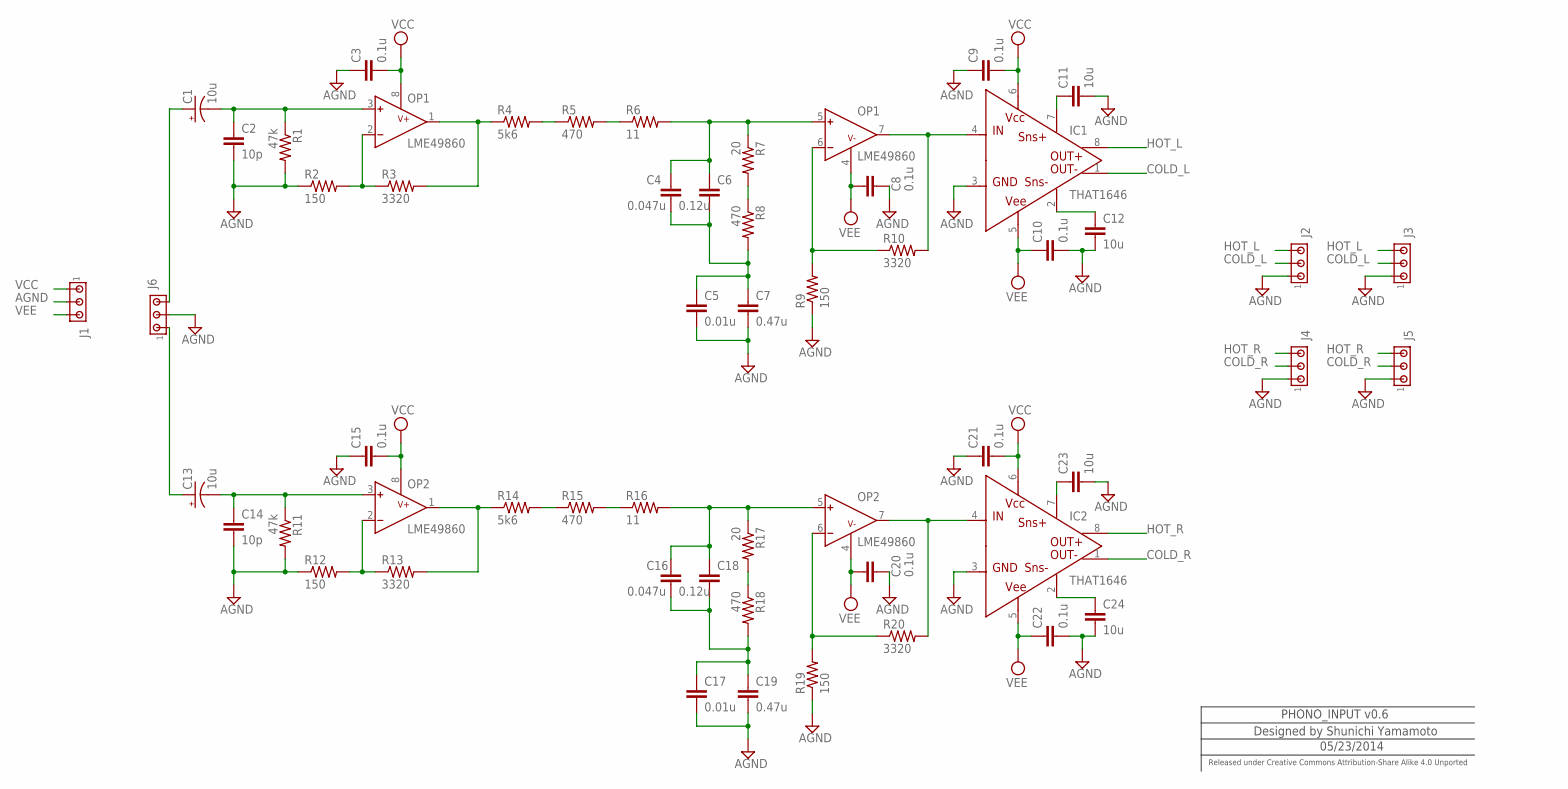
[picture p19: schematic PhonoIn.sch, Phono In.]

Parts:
C1, C13: 10u; UD-5X5,8_NICHICON
C2, C14: 10p; C1608
C3, C8, C9, C10, C15, C20, C21, C22: 0.1u; C2012
C4, C16: 0.047u; C4833
C5, C17: 0.01u; C3216
C6, C18: 0.12u; C6041
C7, C19: 0.47u; C5750
C11, C12, C23, C24: 10u; C2012
IC1, IC2: THAT1646; SOIC8
J1: MTA03-156; 1X3MTA
J2, J3, J4, J5, J6: MTA03-100; 10X03MTA
OP1, OP2: LME49860; SOIC8
R1, R11: 47k; 0805
R2, R9, R12, R19: 150; 0805
R3, R10, R13, R20: 3320; 0805
R4, R14: 5k6; 0805
R5, R8, R15, R18: 470; 0805
R6, R16: 11; 0805
R7, R17: 20; 0805

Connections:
AGND: C2.2, C3.1, C5.2, C7.P$2 (2), C8.2, C9.1, C10.2, C11.2, C12.2, C14.2, C15.1, C17.2, C19.P$2 (2), C20.2, C21.1, C22.2, C23.2, C24.2, IC1.3 (GND), IC2.3 (GND), J1.2, J2.1, J3.1, J4.1, J5.1, J6.2, R1.2, R2.1, R9.1, R11.2, R12.1, R19.1
COLD_L: IC1.1 (OUT-), J2.2, J3.2
COLD_R: IC2.1 (OUT-), J4.2, J5.2
HOT_L: IC1.8 (OUT+), J2.3, J3.3
HOT_R: IC2.8 (OUT+), J4.3, J5.3
unnamed: R5.2, R6.1
unnamed: R15.2, R16.1
unnamed: C11.1, IC1.7 (SNS+)
unnamed: C1.-, C2.1, OP1.3 (INA+), R1.1
unnamed: C13.-, C14.1, OP2.3 (INA+), R11.1
unnamed: C23.1, IC2.7 (SNS+)
unnamed: C12.1, IC1.2 (SNS-)
unnamed: C24.1, IC2.2 (SNS-)
unnamed: OP1.2 (INA-), R2.2, R3.1
unnamed: OP1.1 (OUTA), R3.2, R4.1
unnamed: C4.2, C5.1, C6.2, C7.P$1 (1), R8.2
unnamed: C1.+, J6.3
unnamed: R4.2, R5.1
unnamed: C4.1, C6.1, OP1.5 (INB+), R6.2, R7.1
unnamed: R7.2, R8.1
unnamed: OP1.6 (INB-), R9.2, R10.1
unnamed: C13.+, J6.1
unnamed: OP2.2 (INA-), R12.2, R13.1
unnamed: OP2.1 (OUTA), R13.2, R14.1
unnamed: R14.2, R15.1
unnamed: C16.1, C18.1, OP2.5 (INB+), R16.2, R17.1
unnamed: R17.2, R18.1
unnamed: C16.2, C17.1, C18.2, C19.P$1 (1), R18.2
unnamed: OP2.6 (INB-), R19.2, R20.1
PIN_L: IC1.4 (IN), OP1.7 (OUTB), R10.2
PIN_R: IC2.4 (IN), OP2.7 (OUTB), R20.2
VCC: C3.2, C9.2, C15.2, C21.2, IC1.6 (VCC), IC2.6 (VCC), J1.1, OP1.8 (V+), OP2.8 (V+)
VEE: C8.1, C10.1, C20.1, C22.1, IC1.5 (VEE), IC2.5 (VEE), J1.3, OP1.4 (V-), OP2.4 (V-)

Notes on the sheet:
PHONO_INPUT v0.6
Designed by Shunichi Yamamoto
05/23/2014
Released under Creative Commons Attribution-Share Alike 4.0 Unported

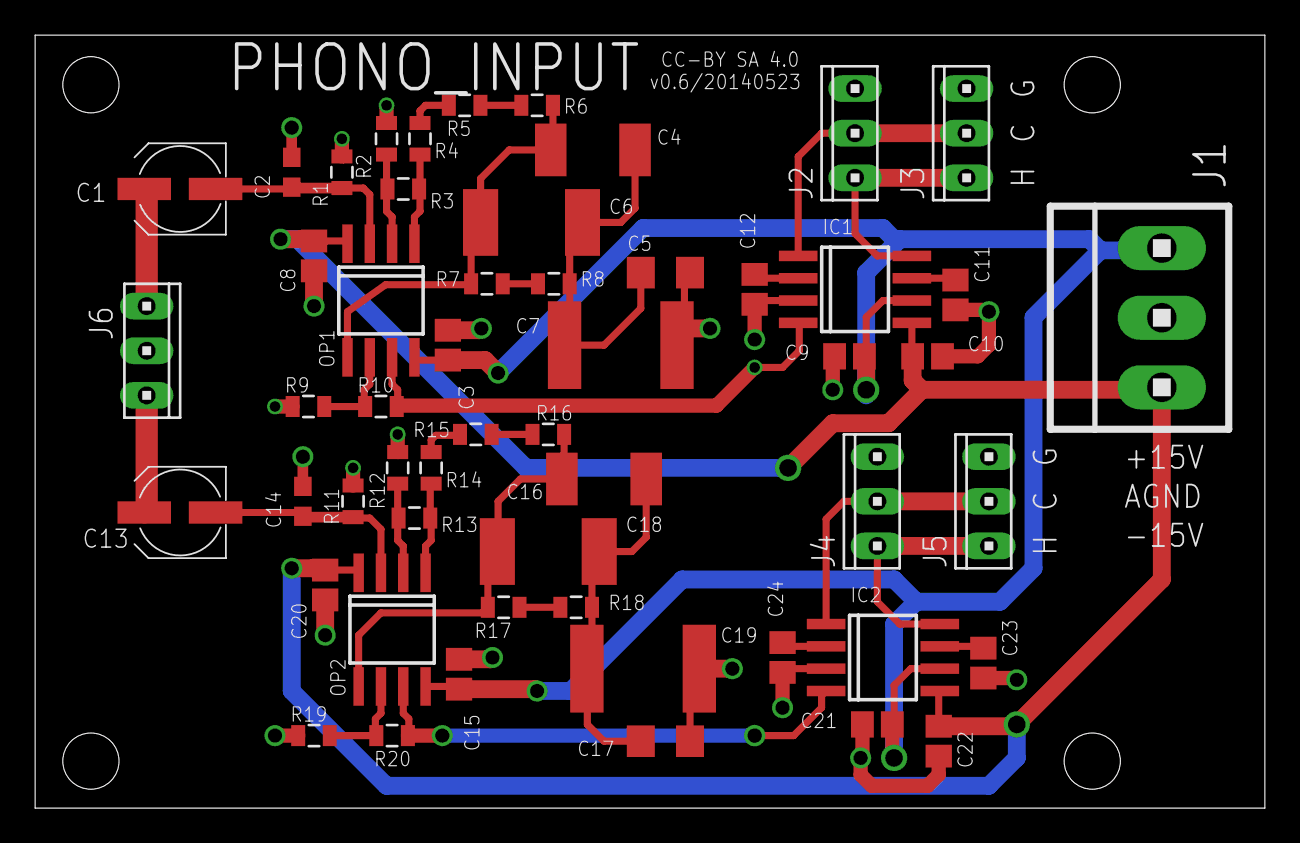
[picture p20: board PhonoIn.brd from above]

Board: 2 copper layers, 70.0 x 44.0 mm, 54 parts (0 on the bottom side), 33 nets.

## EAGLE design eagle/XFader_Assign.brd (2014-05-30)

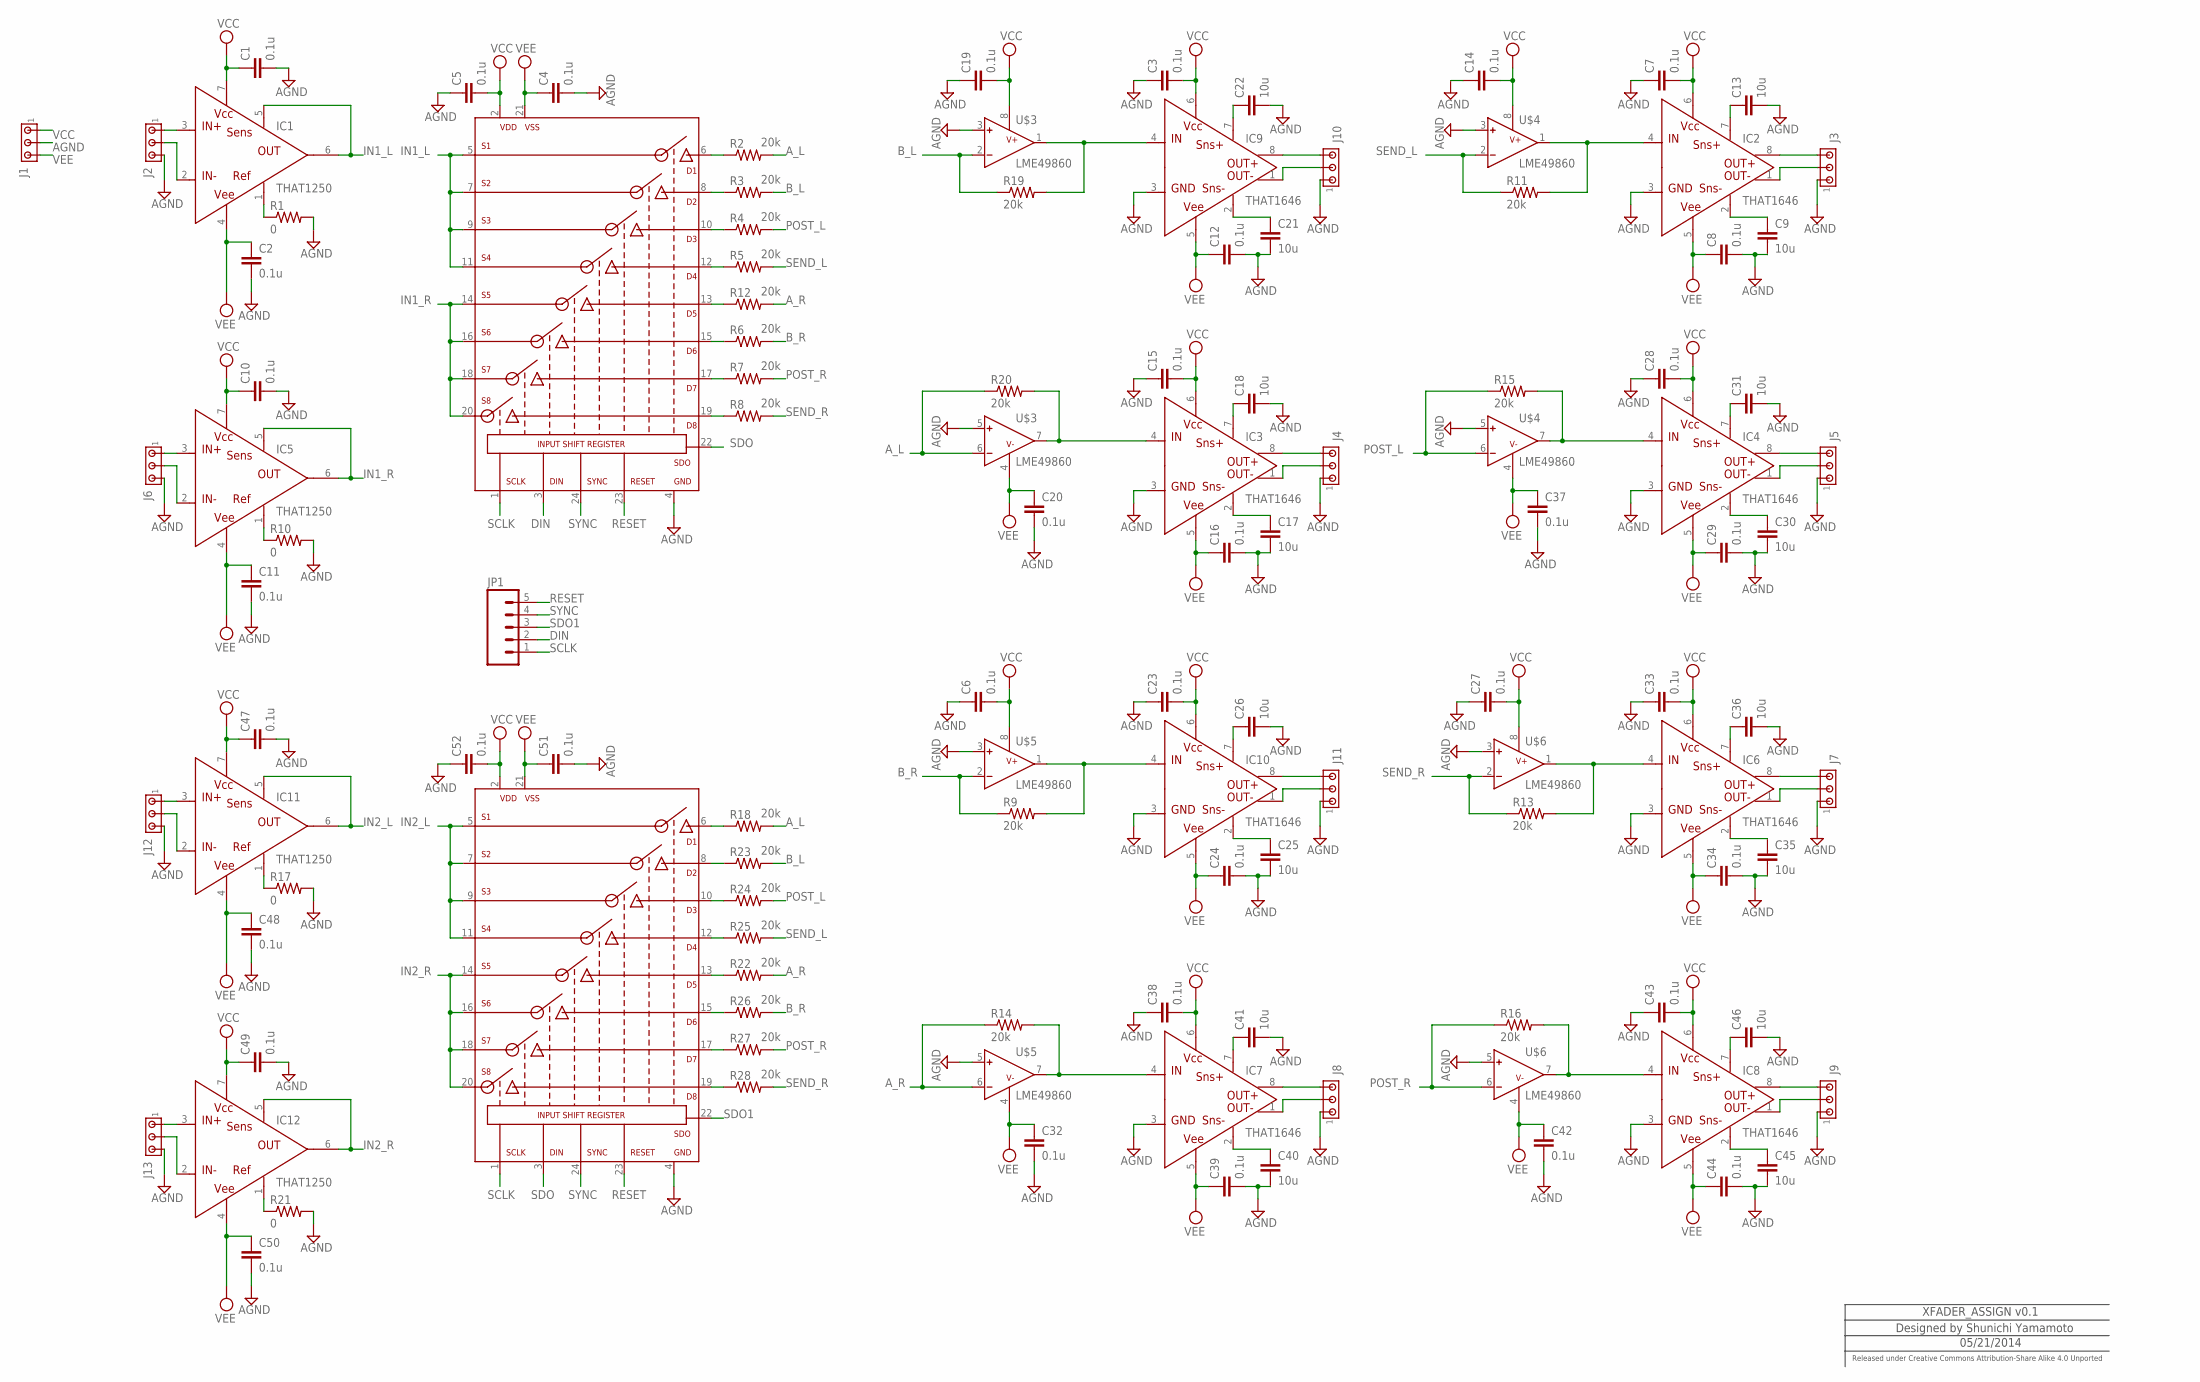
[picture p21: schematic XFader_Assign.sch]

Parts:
C1, C2, C3, C4, C5, C6, C7, C8, C10, C11, C12, C14, C15, C16, C19, C20, C23, C24, C27, C28, C29, C32, C33, C34, C37, C38, C39, C42, C43, C44, C47, C48, C49, C50, C51, C52: 0.1u; C2012
C9, C13, C17, C18, C21, C22, C25, C26, C30, C31, C35, C36, C40, C41, C45, C46: 10u; C2012
IC1, IC5, IC11, IC12: THAT1250; SOIC8@1
IC2, IC3, IC4, IC6, IC7, IC8, IC9, IC10: THAT1646; SOIC8
J1: MTA03-156; 1X3MTA
J2, J3, J4, J5, J6, J7, J8, J9, J10, J11, J12, J13: MTA03-100; 10X03MTA
JP1: M05PTH; 1X05
R1, R10, R17, R21: 0; 0805
R2, R3, R4, R5, R6, R7, R8, R9, R11, R12, R13, R14, R15, R16, R18, R19, R20, R22, R23, R24, R25, R26, R27, R28: 20k; 0805
U$1, U$2: ADG1414; TSSOP24
U$3, U$4, U$5, U$6: LME49860; SOIC8

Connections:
AGND: C1.2, C2.2, C3.1, C4.2, C5.1, C6.1, C7.1, C8.2, C9.2, C10.2, C11.2, C12.2, C13.2, C14.1, C15.1, C16.2, C17.2, C18.2, C19.1, C20.2, C21.2, C22.2, C23.1, C24.2, C25.2, C26.2, C27.1, C28.1, C29.2, C30.2, C31.2, C32.2, C33.1, C34.2, C35.2, C36.2, C37.2, C38.1, C39.2, C40.2, C41.2, C42.2, C43.1, C44.2, C45.2, C46.2, C47.2, C48.2, C49.2, C50.2, C51.2, C52.1, IC2.3 (GND), IC3.3 (GND), IC4.3 (GND), IC6.3 (GND), IC7.3 (GND), IC8.3 (GND), IC9.3 (GND), IC10.3 (GND), J1.2, J2.3, J3.1, J4.1, J5.1, J6.3, J7.1, J8.1, J9.1, J10.1, J11.1, J12.3, J13.3, R1.2, R10.2, R17.2, R21.2, U$1.4 (GND), U$2.4 (GND), U$3.3 (INA+), U$3.5 (INB+), U$4.3 (INA+), U$4.5 (INB+), U$5.3 (INA+), U$5.5 (INB+), U$6.3 (INA+), U$6.5 (INB+)
A_L: R2.2, R18.2, R20.1, U$3.6 (INB-)
A_R: R12.2, R14.1, R22.2, U$5.6 (INB-)
B_L: R3.2, R19.1, R23.2, U$3.2 (INA-)
B_R: R6.2, R9.1, R26.2, U$5.2 (INA-)
DIN: JP1.2, U$1.3 (DIN)
IN1_L: IC1.5 (SENS), IC1.6 (OUT), U$1.5 (S1), U$1.7 (S2), U$1.9 (S3), U$1.11 (S4)
IN1_R: IC5.5 (SENS), IC5.6 (OUT), U$1.14 (S5), U$1.16 (S6), U$1.18 (S7), U$1.20 (S8)
IN2_L: IC11.5 (SENS), IC11.6 (OUT), U$2.5 (S1), U$2.7 (S2), U$2.9 (S3), U$2.11 (S4)
IN2_R: IC12.5 (SENS), IC12.6 (OUT), U$2.14 (S5), U$2.16 (S6), U$2.18 (S7), U$2.20 (S8)
MGAIN_L1: IC10.4 (IN), R9.2, U$5.1 (OUTA)
MGAIN_L2: IC9.4 (IN), R19.2, U$3.1 (OUTA)
MGAIN_L3: IC2.4 (IN), R11.2, U$4.1 (OUTA)
MGAIN_L4: IC6.4 (IN), R13.2, U$6.1 (OUTA)
MGAIN_R: IC3.4 (IN), R20.2, U$3.7 (OUTB)
MGAIN_R1: IC7.4 (IN), R14.2, U$5.7 (OUTB)
MGAIN_R2: IC4.4 (IN), R15.2, U$4.7 (OUTB)
MGAIN_R3: IC8.4 (IN), R16.2, U$6.7 (OUTB)
unnamed: IC1.1 (REF), R1.1
unnamed: R2.1, U$1.6 (D1)
unnamed: IC1.3 (IN+), J2.1
unnamed: IC1.2 (IN-), J2.2
unnamed: R12.1, U$1.13 (D5)
unnamed: R3.1, U$1.8 (D2)
unnamed: R4.1, U$1.10 (D3)
unnamed: R5.1, U$1.12 (D4)
unnamed: R6.1, U$1.15 (D6)
unnamed: R7.1, U$1.17 (D7)
unnamed: R8.1, U$1.19 (D8)
unnamed: C13.1, IC2.7 (SNS+)
unnamed: IC5.1 (REF), R10.1
unnamed: IC5.3 (IN+), J6.1
unnamed: IC5.2 (IN-), J6.2
unnamed: C9.1, IC2.2 (SNS-)
unnamed: IC2.8 (OUT+), J3.3
unnamed: IC2.1 (OUT-), J3.2
unnamed: C18.1, IC3.7 (SNS+)
unnamed: C17.1, IC3.2 (SNS-)
unnamed: IC3.8 (OUT+), J4.3
unnamed: IC3.1 (OUT-), J4.2
unnamed: C31.1, IC4.7 (SNS+)
unnamed: C30.1, IC4.2 (SNS-)
unnamed: C22.1, IC9.7 (SNS+)
unnamed: IC9.8 (OUT+), J10.3
unnamed: IC9.1 (OUT-), J10.2
unnamed: C26.1, IC10.7 (SNS+)
unnamed: C25.1, IC10.2 (SNS-)
unnamed: IC10.8 (OUT+), J11.3
unnamed: IC10.1 (OUT-), J11.2
unnamed: IC4.8 (OUT+), J5.3
unnamed: IC4.1 (OUT-), J5.2
unnamed: C21.1, IC9.2 (SNS-)
unnamed: C36.1, IC6.7 (SNS+)
unnamed: C35.1, IC6.2 (SNS-)
unnamed: IC6.8 (OUT+), J7.3
unnamed: IC6.1 (OUT-), J7.2
unnamed: C41.1, IC7.7 (SNS+)
unnamed: C40.1, IC7.2 (SNS-)
unnamed: IC7.8 (OUT+), J8.3
unnamed: IC7.1 (OUT-), J8.2
unnamed: C46.1, IC8.7 (SNS+)
unnamed: C45.1, IC8.2 (SNS-)
unnamed: IC8.8 (OUT+), J9.3
unnamed: IC8.1 (OUT-), J9.2
unnamed: IC11.1 (REF), R17.1
unnamed: IC11.3 (IN+), J12.1
unnamed: IC11.2 (IN-), J12.2
unnamed: IC12.1 (REF), R21.1
unnamed: IC12.3 (IN+), J13.1
unnamed: IC12.2 (IN-), J13.2
unnamed: R18.1, U$2.6 (D1)
unnamed: R22.1, U$2.13 (D5)
unnamed: R23.1, U$2.8 (D2)
unnamed: R24.1, U$2.10 (D3)
unnamed: R25.1, U$2.12 (D4)
unnamed: R26.1, U$2.15 (D6)
unnamed: R27.1, U$2.17 (D7)
unnamed: R28.1, U$2.19 (D8)
POST_L: R4.2, R15.1, R24.2, U$4.6 (INB-)
POST_R: R7.2, R16.1, R27.2, U$6.6 (INB-)
RESET: JP1.5, U$1.23 (RESET), U$2.23 (RESET)
SCLK: JP1.1, U$1.1 (SCLK), U$2.1 (SCLK)
SDO: U$1.22 (SDO), U$2.3 (DIN)
SDO1: JP1.3, U$2.22 (SDO)
SEND_L: R5.2, R11.1, R25.2, U$4.2 (INA-)
SEND_R: R8.2, R13.1, R28.2, U$6.2 (INA-)
SYNC: JP1.4, U$1.24 (SYNC), U$2.24 (SYNC)
VCC: C1.1, C3.2, C5.2, C6.2, C7.2, C10.1, C14.2, C15.2, C19.2, C23.2, C27.2, C28.2, C33.2, C38.2, C43.2, C47.1, C49.1, C52.2, IC1.7 (VCC), IC2.6 (VCC), IC3.6 (VCC), IC4.6 (VCC), IC5.7 (VCC), IC6.6 (VCC), IC7.6 (VCC), IC8.6 (VCC), IC9.6 (VCC), IC10.6 (VCC), IC11.7 (VCC), IC12.7 (VCC), J1.1, U$1.2 (VDD), U$2.2 (VDD), U$3.8 (V+), U$4.8 (V+), U$5.8 (V+), U$6.8 (V+)
VEE: C2.1, C4.1, C8.1, C11.1, C12.1, C16.1, C20.1, C24.1, C29.1, C32.1, C34.1, C37.1, C39.1, C42.1, C44.1, C48.1, C50.1, C51.1, IC1.4 (VEE), IC2.5 (VEE), IC3.5 (VEE), IC4.5 (VEE), IC5.4 (VEE), IC6.5 (VEE), IC7.5 (VEE), IC8.5 (VEE), IC9.5 (VEE), IC10.5 (VEE), IC11.4 (VEE), IC12.4 (VEE), J1.3, U$1.21 (VSS), U$2.21 (VSS), U$3.4 (V-), U$4.4 (V-), U$5.4 (V-), U$6.4 (V-)

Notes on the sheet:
XFADER_ASSIGN v0.1
Designed by Shunichi Yamamoto
05/21/2014
Released under Creative Commons Attribution-Share Alike 4.0 Unported

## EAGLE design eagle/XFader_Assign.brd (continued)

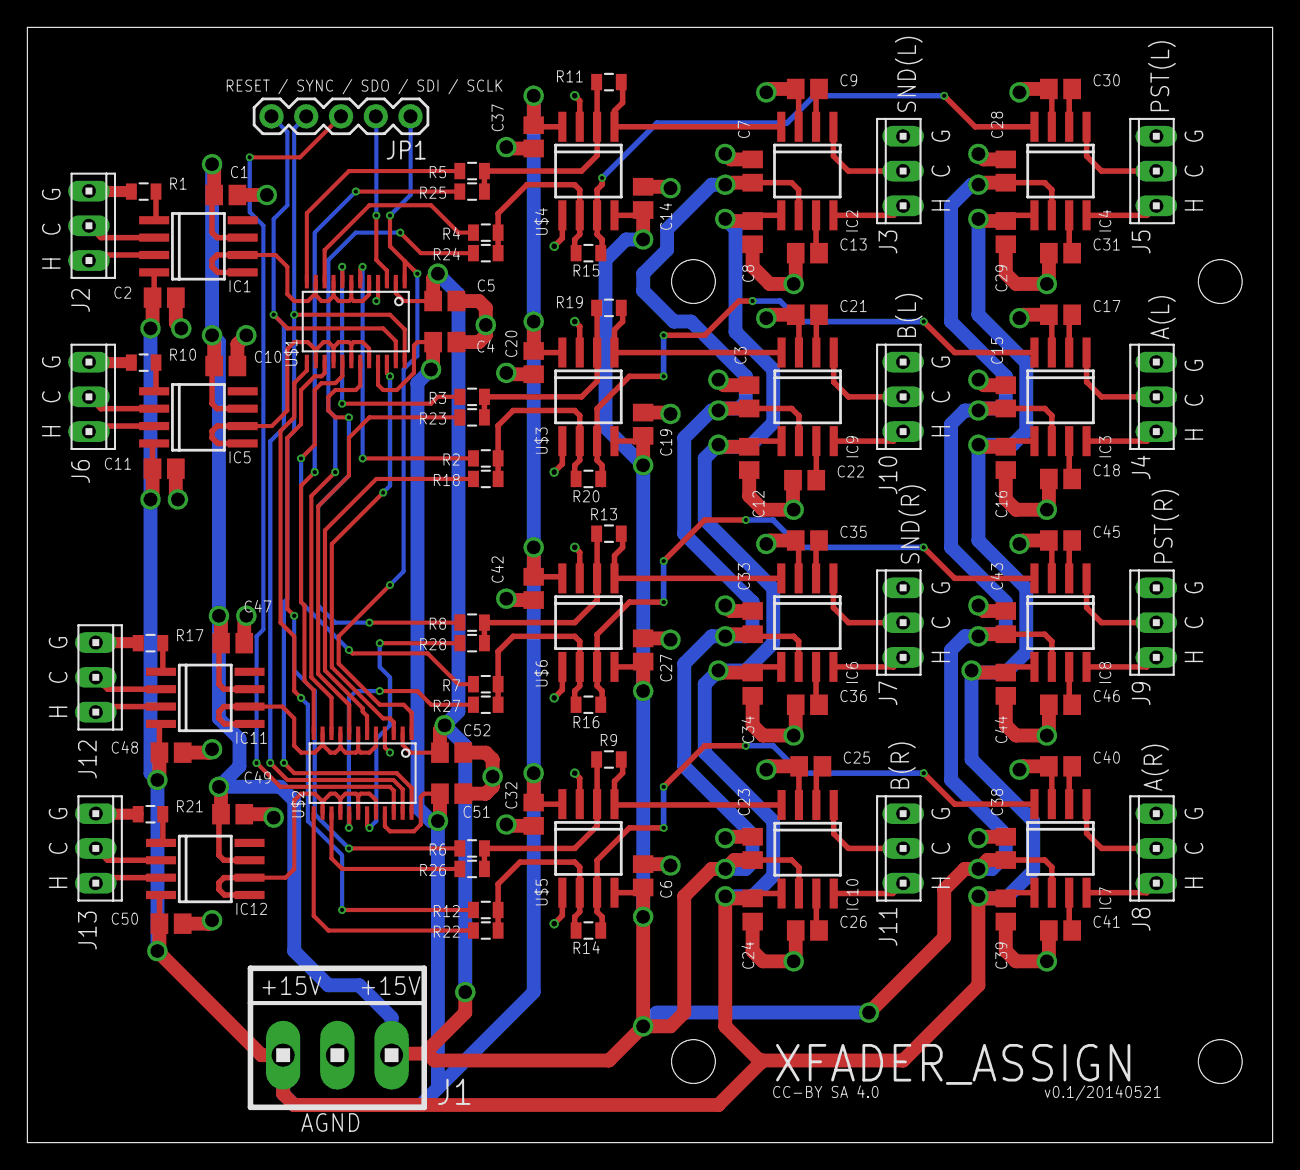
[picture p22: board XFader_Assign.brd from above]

Board: 4 copper layers, 91.0 x 81.5 mm, 112 parts (0 on the bottom side), 89 nets.

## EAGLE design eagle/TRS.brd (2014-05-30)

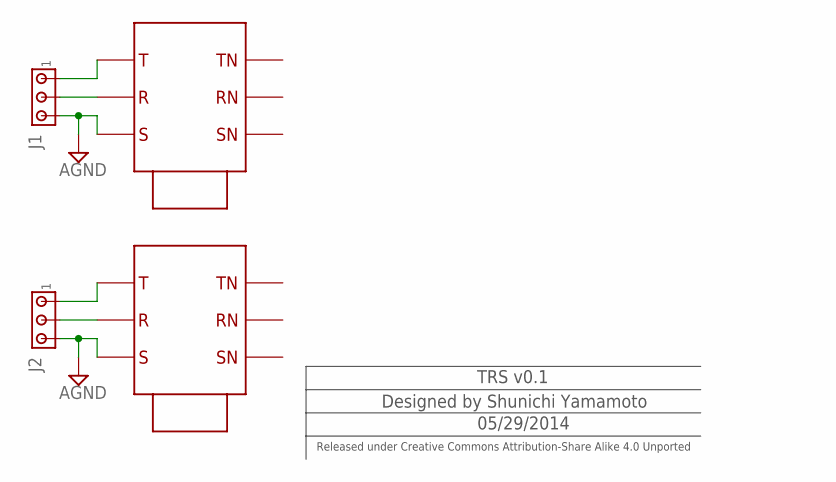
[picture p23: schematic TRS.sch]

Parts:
J1, J2: MTA03-100; 10X03MTA
X1, X2: NMJ6HFD2

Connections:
AGND: J1.3, J2.3, X1.GND-IN, X2.GND-IN
unnamed: J1.1, X1.LEFT-IN
unnamed: J1.2, X1.RIGHT-IN
unnamed: J2.1, X2.LEFT-IN
unnamed: J2.2, X2.RIGHT-IN

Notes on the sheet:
TRS v0.1
Designed by Shunichi Yamamoto
05/29/2014
Released under Creative Commons Attribution-Share Alike 4.0 Unported

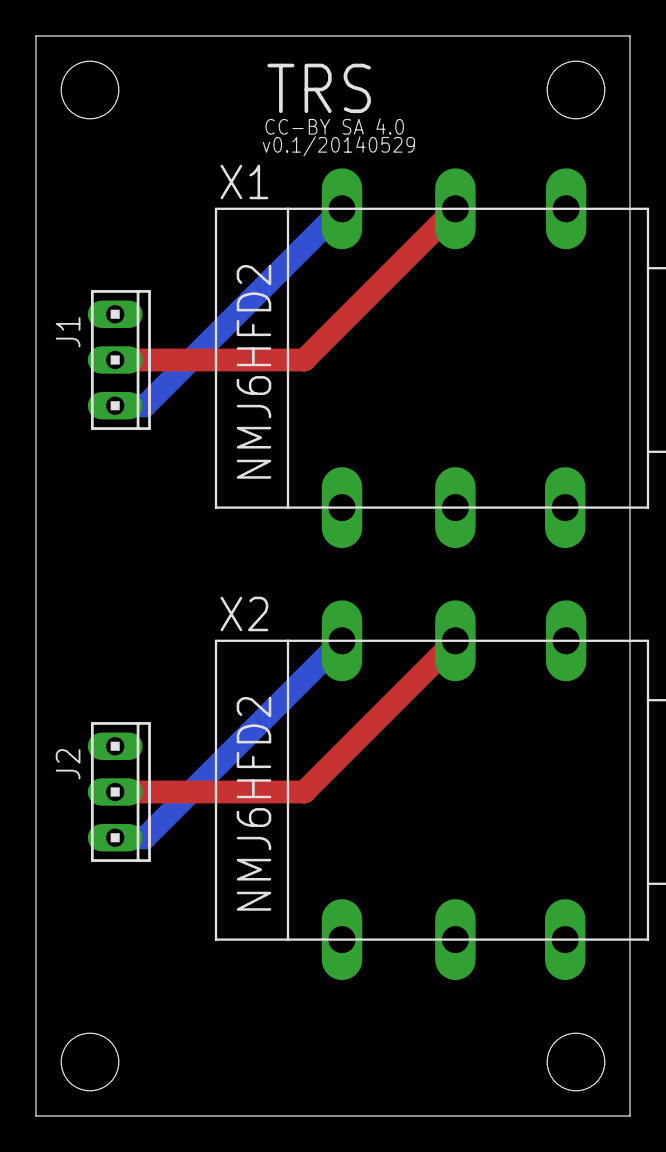
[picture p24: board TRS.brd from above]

Board: 2 copper layers, 33.0 x 60.0 mm, 4 parts (0 on the bottom side), 5 nets.

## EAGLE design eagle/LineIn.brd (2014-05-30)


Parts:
C1, C7: 10u; UD-5X5,8_NICHICON
C2, C3, C4, C8, C9, C10: 0.1u; C2012
C5, C6, C11, C12: 10u; C2012
IC1, IC2: THAT1646; SOIC8
J1: MTA03-156; 1X3MTA
J2, J3, J4, J5, J6: MTA03-100; 10X03MTA
OP1: LME49860; SOIC8@1
R1, R2: 47k; 0805

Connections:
AGND: C2.1, C3.1, C4.2, C5.2, C6.2, C8.2, C9.1, C10.2, C11.2, C12.2, IC1.3 (GND), IC2.3 (GND), J1.2, J2.1, J3.1, J4.1, J5.1, J6.2, R1.2, R2.2
COLD_L: IC1.1 (OUT-), J2.2, J3.2
COLD_R: IC2.1 (OUT-), J4.2, J5.2
HOT_L: IC1.8 (OUT+), J2.3, J3.3
HOT_R: IC2.8 (OUT+), J4.3, J5.3
LIN_L: IC1.4 (IN), OP1.1 (OUTA), OP1.2 (INA-)
LIN_R: IC2.4 (IN), OP1.6 (INB-), OP1.7 (OUTB)
unnamed: C1.+, J6.3
unnamed: C1.-, OP1.3 (INA+), R1.1
unnamed: C7.+, J6.1
unnamed: C5.1, IC1.7 (SNS+)
unnamed: C7.-, OP1.5 (INB+), R2.1
unnamed: C11.1, IC2.7 (SNS+)
unnamed: C6.1, IC1.2 (SNS-)
unnamed: C12.1, IC2.2 (SNS-)
VCC: C2.2, C3.2, C9.2, IC1.6 (VCC), IC2.6 (VCC), J1.1, OP1.8 (V+)
VEE: C4.1, C8.1, C10.1, IC1.5 (VEE), IC2.5 (VEE), J1.3, OP1.4 (V-)

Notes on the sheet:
LINE_INPUT v0.3
Designed by Shunichi Yamamoto
05/23/2014
Released under Creative Commons Attribution-Share Alike 4.0 Unported


Board: 2 copper layers, 70.0 x 44.0 mm, 23 parts (0 on the bottom side), 17 nets.

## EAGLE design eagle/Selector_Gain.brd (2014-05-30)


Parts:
C1, C2, C3, C4, C5, C6, C7, C8, C9, C10: 0.1u; C2012
IC1, IC2, IC3, IC4: THAT1250; SOIC8
IC5: ADG1433; TSSOP16
J1: MTA03-156; 1X3MTA
J2, J3, J4, J5: MTA03-100; 10X03MTA
JP1: M02PTH; 1X02
R1, R2, R3, R4: 0; 0805

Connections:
AGND: C1.2, C2.2, C3.2, C4.2, C5.2, C6.2, C7.2, C8.2, C9.2, C10.2, IC5.14 (EN), IC5.16 (GND), J1.2, J2.3, J3.3, J4.3, J5.3, R1.2, R2.2, R3.2, R4.2; also elsewhere on the board
IN1: IC5.15 (IN1), JP1.1
IN2: IC5.8 (IN2), JP1.2
IN_L: IC5.3 (D1); also elsewhere on the board
IN_R: IC5.6 (D2); also elsewhere on the board
LIN_L: IC3.5 (SENS), IC3.6 (OUT), IC5.4 (S1B)
LIN_R: IC4.5 (SENS), IC4.6 (OUT), IC5.5 (S2B)
unnamed: IC1.1 (REF), R1.1
unnamed: IC3.1 (REF), R3.1
unnamed: IC1.3 (IN+), J2.1
unnamed: IC1.2 (IN-), J2.2
unnamed: IC2.1 (REF), R2.1
unnamed: IC3.3 (IN+), J4.1
unnamed: IC2.3 (IN+), J3.1
unnamed: IC2.2 (IN-), J3.2
unnamed: IC3.2 (IN-), J4.2
unnamed: IC4.1 (REF), R4.1
unnamed: IC4.3 (IN+), J5.1
unnamed: IC4.2 (IN-), J5.2
PIN_L: IC1.5 (SENS), IC1.6 (OUT), IC5.2 (S1A)
PIN_R: IC2.5 (SENS), IC2.6 (OUT), IC5.7 (S2A)
VCC: C1.1, C3.1, C5.1, C7.1, C9.1, IC1.7 (VCC), IC2.7 (VCC), IC3.7 (VCC), IC4.7 (VCC), IC5.1 (VDD), J1.1; also elsewhere on the board
VEE: C2.1, C4.1, C6.1, C8.1, C10.1, IC1.4 (VEE), IC2.4 (VEE), IC3.4 (VEE), IC4.4 (VEE), IC5.13 (VSS), J1.3; also elsewhere on the board

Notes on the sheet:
SELECTOR/GAIN v0.3
Designed by Shunichi Yamamoto
05/16/2014
Released under Creative Commons Attribution-Share Alike 4.0 Unported


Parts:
C11, C20: 10u; UD-5X5,8_NICHICON
C12, C21: 100p; C2012
C13, C14, C16, C17, C22, C24, C25, C26, C30, C31, C33, C34: 0.1u; C2012
C15, C23: 22p; C2012
C18, C19, C27, C28: 10u; C2012
C29, C32: 2u2; UD-5X5,8_NICHICON
IC6, IC7: THAT1646; SOIC8
J6, J7: MTA03-100; 10X03MTA
JP2: M02PTH; 1X02
OP1, OP2: LME49860; SOIC8
R5, R8: 20k; 0805
R6, R9: 6k81; 0805
R7, R10: 14k3; 0805
R11, R15: 6k34; 0805
R12, R17: 28k; 0805
R13, R16: 312k; 0805
R14, R18: 2k; 0805
VCA1: THAT2162; QSOP-16

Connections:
AGND: C12.2, C13.1, C14.1, C16.1, C17.2, C18.2, C19.2, C21.2, C22.2, C24.2, C25.1, C26.2, C27.2, C28.2, C29.-, C30.1, C32.-, C34.2, IC6.3 (GND), IC7.3 (GND), J6.1, J7.1, OP1.3 (INA+), OP1.5 (INB+), OP2.3 (INA+), OP2.5 (INB+), VCA1.4 (EC1-), VCA1.8 (GND), VCA1.13 (EC2-); also elsewhere on the board
CV_GAIN_L: C31.2, OP2.1 (OUTA), R14.2, VCA1.6 (EC1+)
CV_GAIN_R: C33.2, OP2.7 (OUTB), R18.2, VCA1.11 (EC2+)
DAC1_GAIN: JP2.2, R11.1
DAC2_GAIN: JP2.1, R15.1
IN_L: C11.+; also elsewhere on the board
IN_R: C20.+; also elsewhere on the board
unnamed: IC6.8 (OUT+), J6.3
unnamed: IC6.1 (OUT-), J6.2
unnamed: IC7.8 (OUT+), J7.3
unnamed: IC7.1 (OUT-), J7.2
unnamed: R5.2, R6.1, VCA1.7 (IN1)
unnamed: C11.-, R5.1
unnamed: C18.1, IC6.7 (SNS+)
unnamed: C19.1, IC6.2 (SNS-)
unnamed: C27.1, IC7.7 (SNS+)
unnamed: C28.1, IC7.2 (SNS-)
unnamed: R8.2, R9.1, VCA1.10 (IN2)
unnamed: C20.-, R8.1
unnamed: C12.1, R6.2
unnamed: C15.1, OP1.2 (INA-), R7.1, VCA1.2 (OUT1)
unnamed: C21.1, R9.2
unnamed: C29.+, R11.2, R12.1
unnamed: C31.1, OP2.2 (INA-), R12.2, R13.2, R14.1
unnamed: C32.+, R15.2, R17.1
unnamed: C33.1, OP2.6 (INB-), R16.2, R17.2, R18.1
unnamed: C23.1, OP1.6 (INB-), R10.1, VCA1.15 (OUT2)
OUT_L: C15.2, IC6.4 (IN), OP1.1 (OUTA), R7.2
OUT_R: C23.2, IC7.4 (IN), OP1.7 (OUTB), R10.2
VCC: C13.2, C14.2, C16.2, C25.2, C30.2, IC6.6 (VCC), IC7.6 (VCC), OP1.8 (V+), OP2.8 (V+), VCA1.12 (V+); also elsewhere on the board
VEE: C17.1, C22.1, C24.1, C26.1, C34.1, IC6.5 (VEE), IC7.5 (VEE), OP1.4 (V-), OP2.4 (V-), R13.1, R16.1, VCA1.5 (V-); also elsewhere on the board


Board: 2 copper layers, 82.0 x 51.0 mm, 71 parts (0 on the bottom side), 49 nets.

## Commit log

2014-05-29 Add schematic and board datas.
2014-05-30 Added the eagle files(.sch and .brd).
    [Gain.brd, Gain.sch, HeadphoneOut.brd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]

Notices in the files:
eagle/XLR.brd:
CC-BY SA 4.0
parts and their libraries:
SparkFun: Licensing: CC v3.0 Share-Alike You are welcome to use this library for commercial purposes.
